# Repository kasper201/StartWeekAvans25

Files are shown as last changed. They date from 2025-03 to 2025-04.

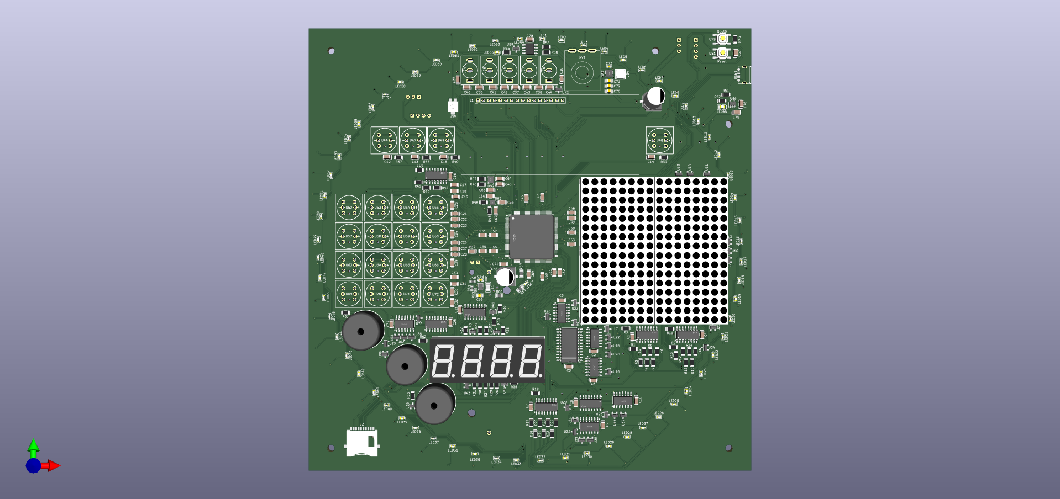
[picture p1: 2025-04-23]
PCB design/PCB_V2/PCB PNG/Top_view.png

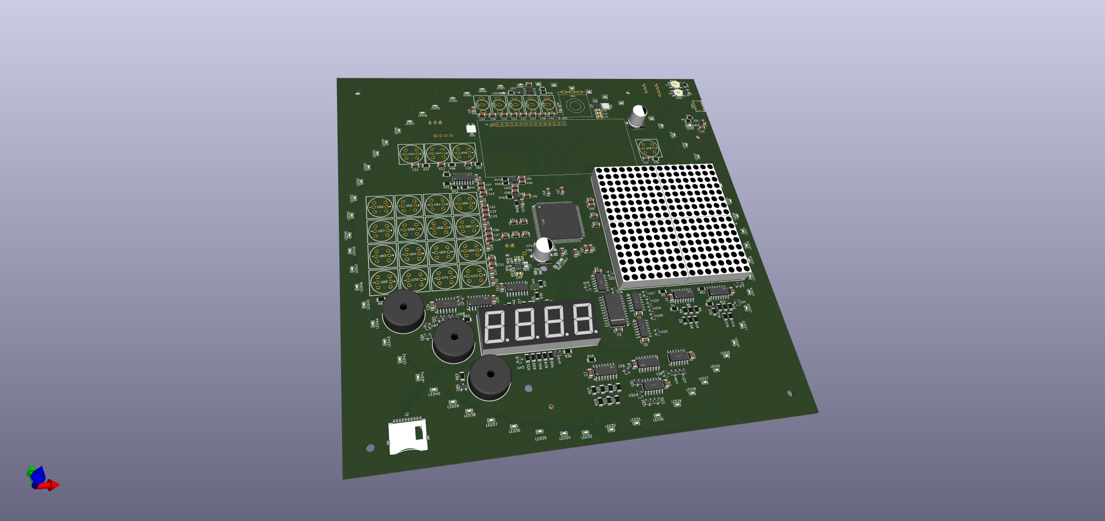
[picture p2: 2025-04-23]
PCB design/PCB_V2/PCB PNG/Side_view.png

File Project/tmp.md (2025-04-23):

# Issues found

# simulator
- printk stops working inside minigame code due to threads?

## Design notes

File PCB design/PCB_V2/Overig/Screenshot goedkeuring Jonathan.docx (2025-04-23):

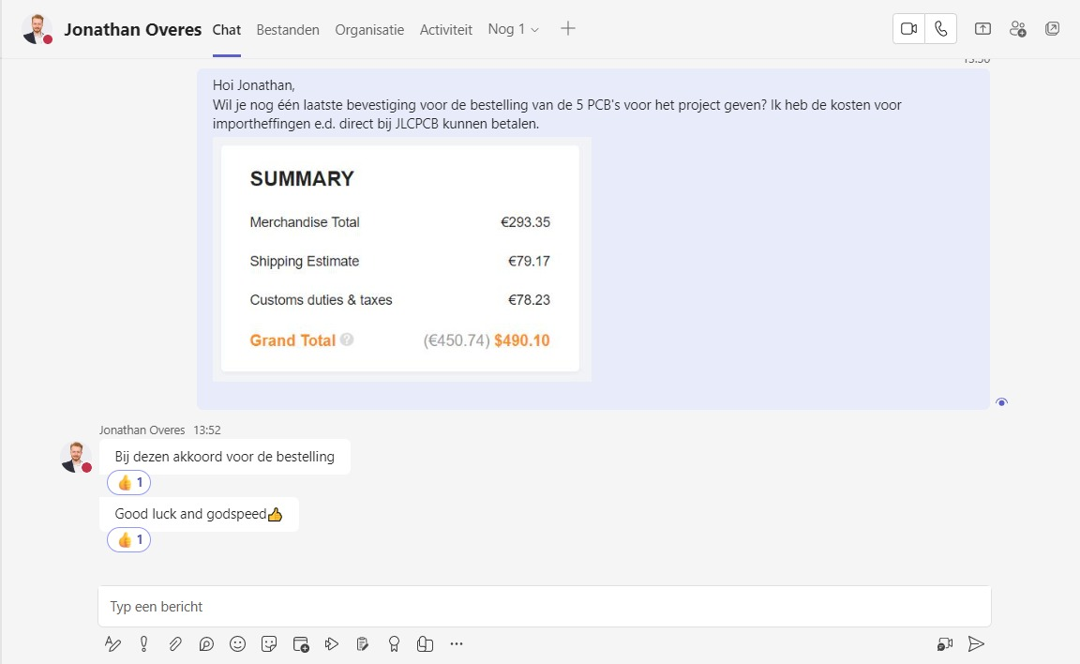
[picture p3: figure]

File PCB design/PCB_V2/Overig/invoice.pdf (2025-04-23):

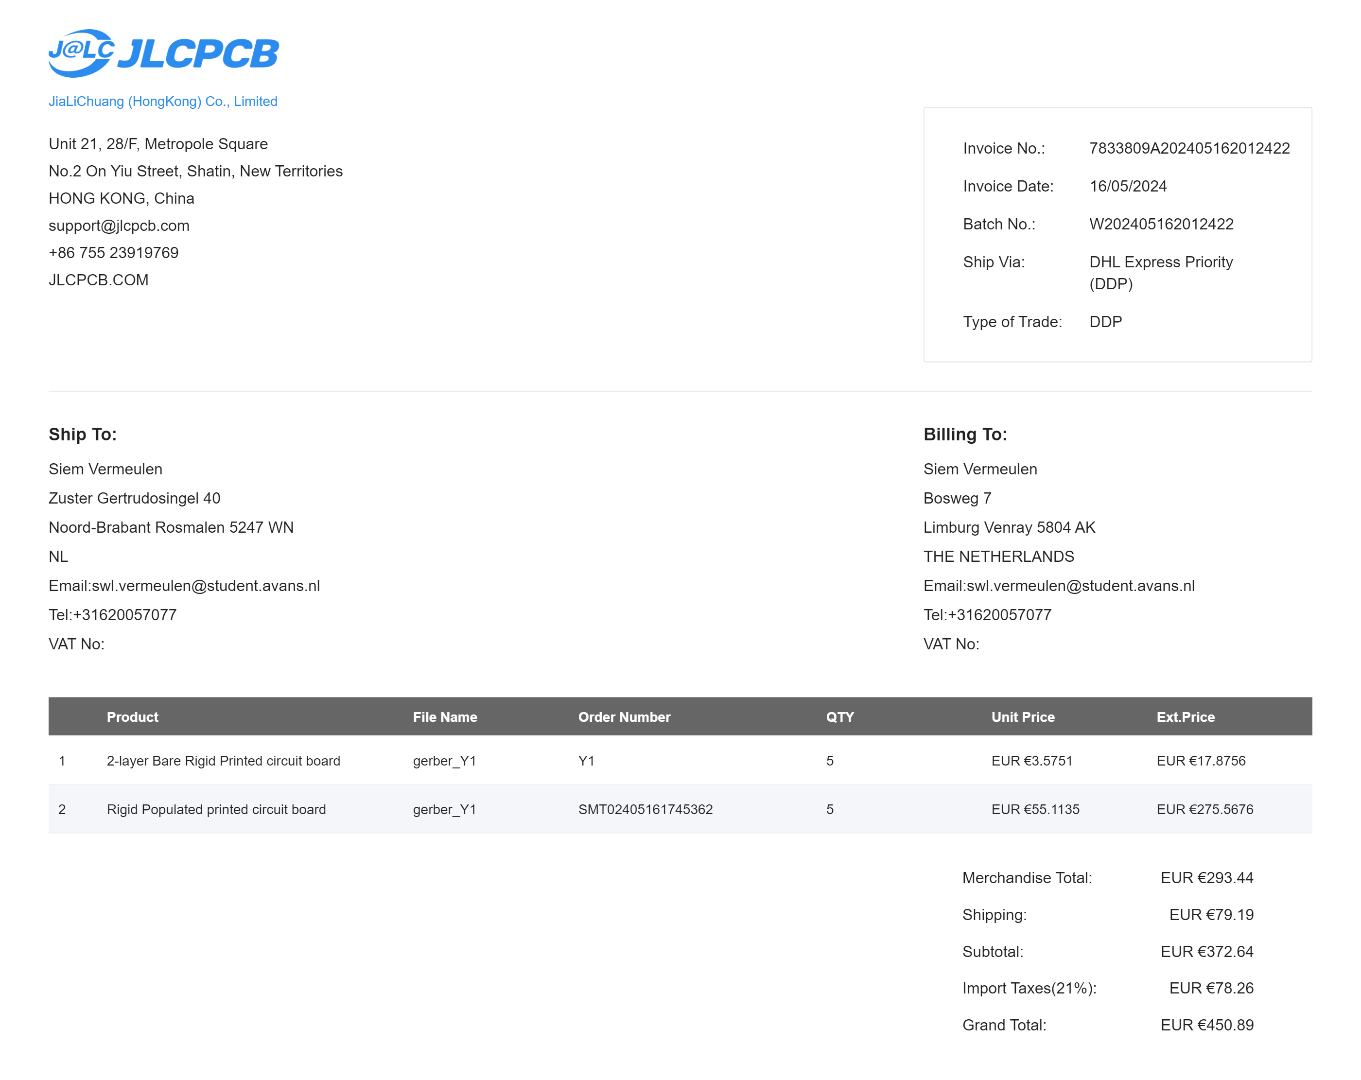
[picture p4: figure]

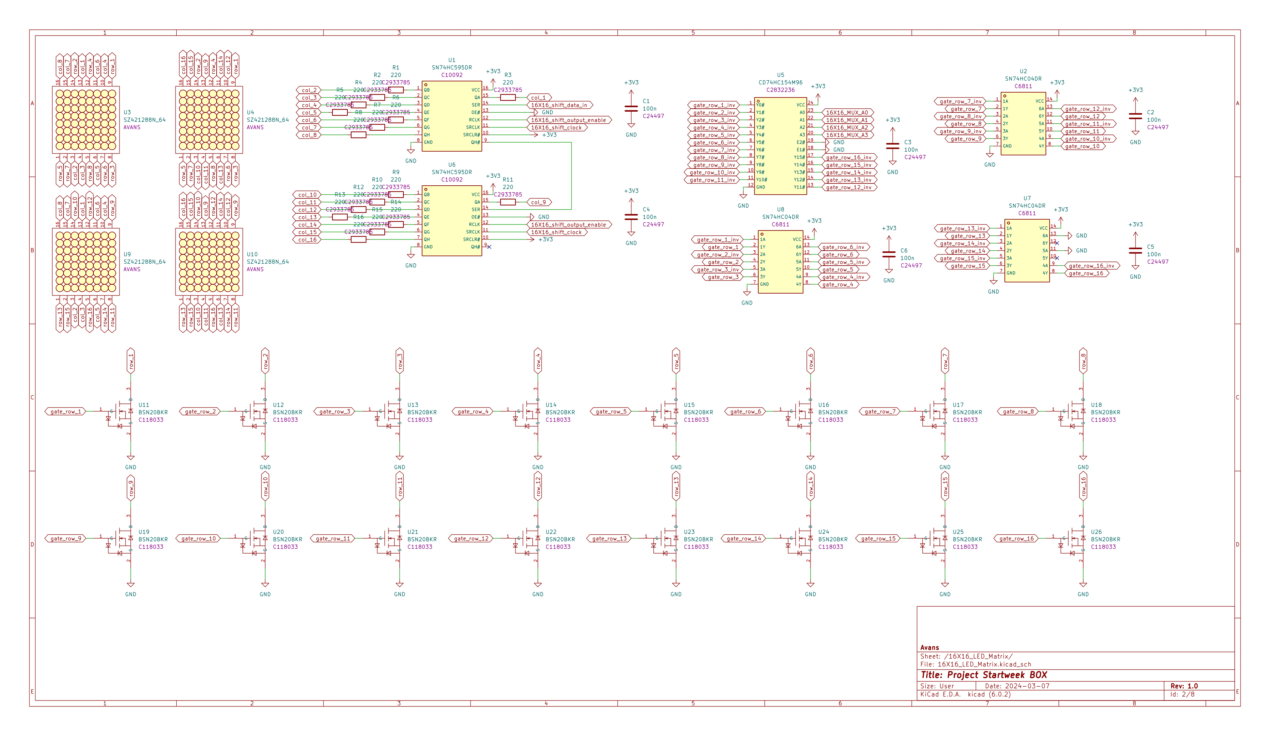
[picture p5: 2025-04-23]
PCB design/PCB_V2/Schematic PNG/PCB_V2-2.png

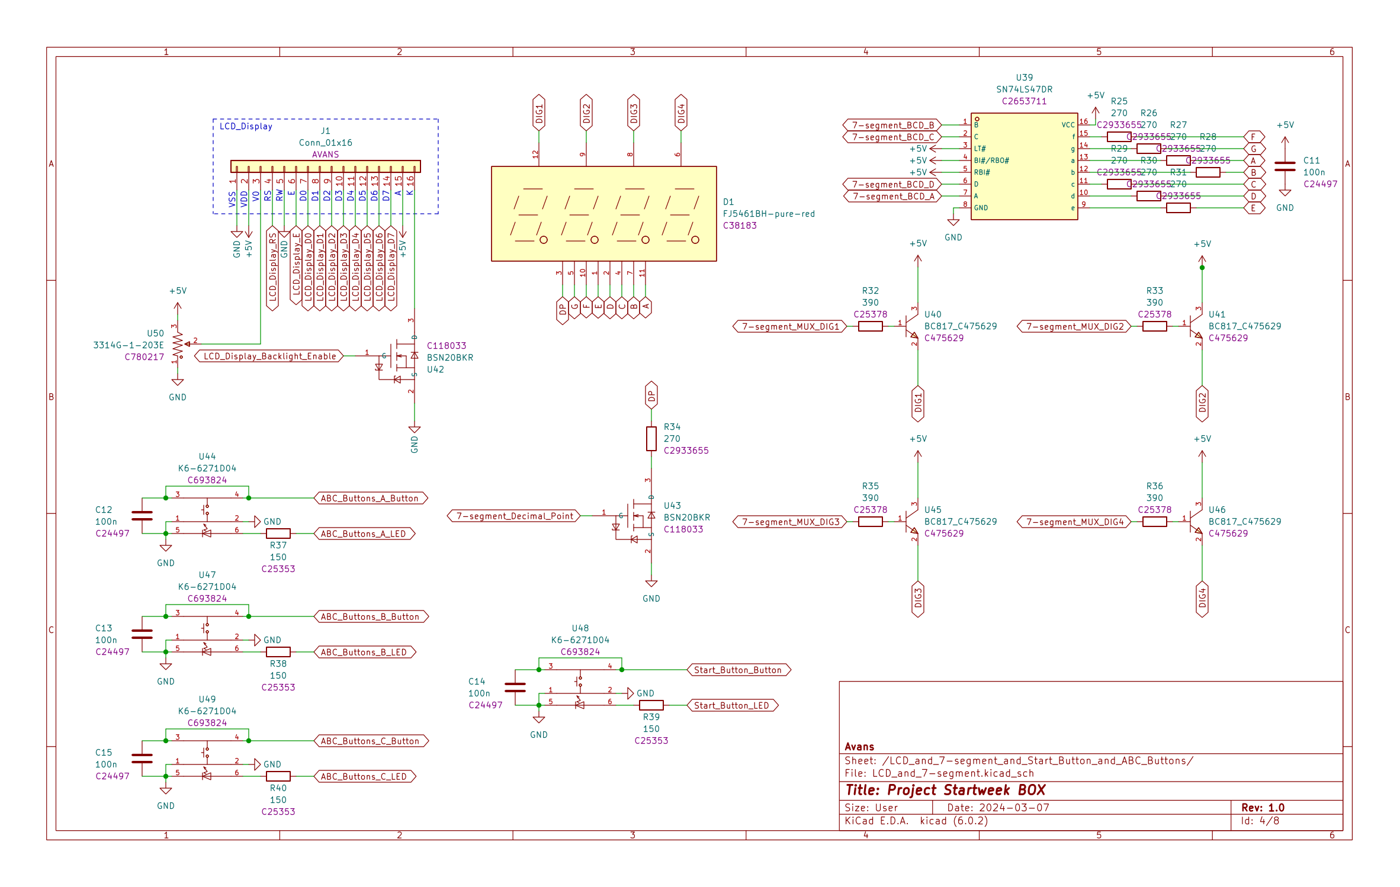
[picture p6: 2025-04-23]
PCB design/PCB_V2/Schematic PNG/PCB_V2-4.png

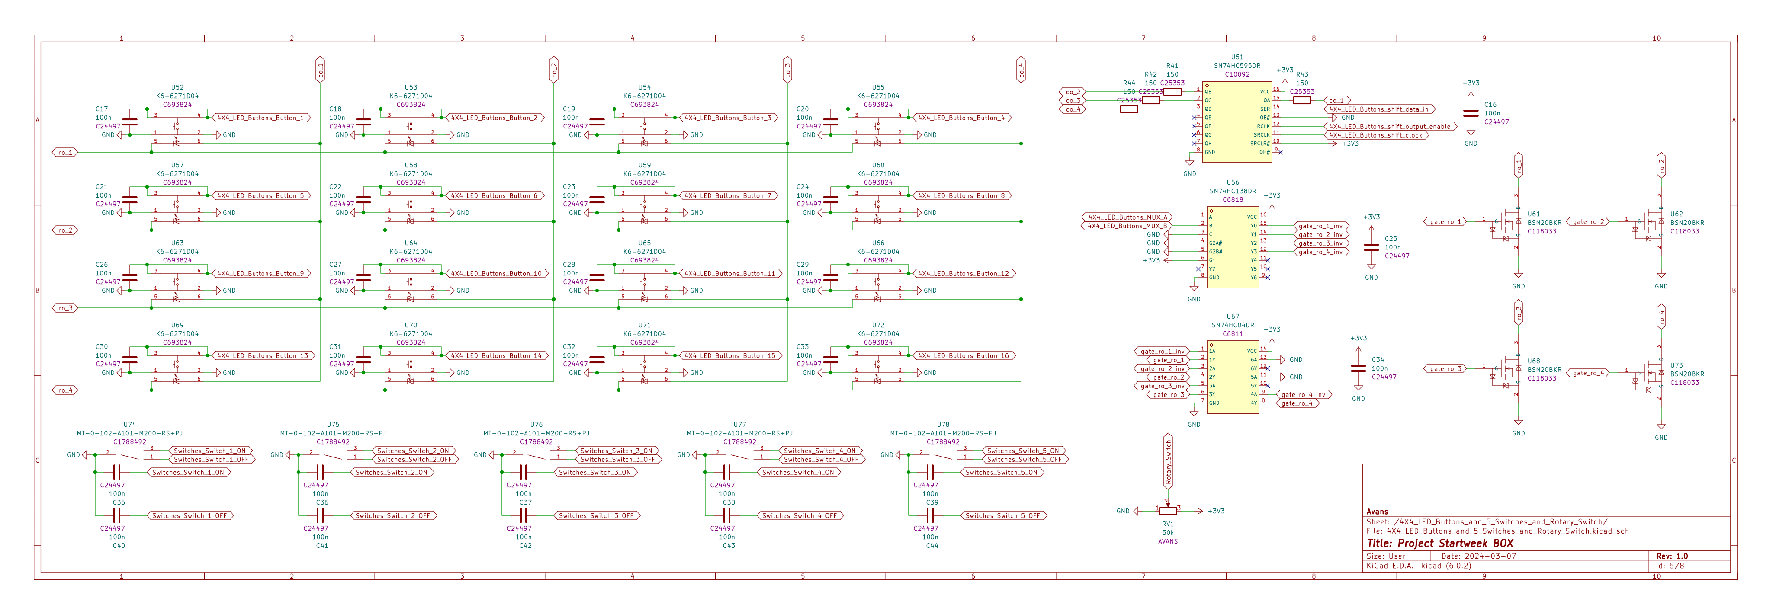
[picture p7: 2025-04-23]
PCB design/PCB_V2/Schematic PNG/PCB_V2-5.png

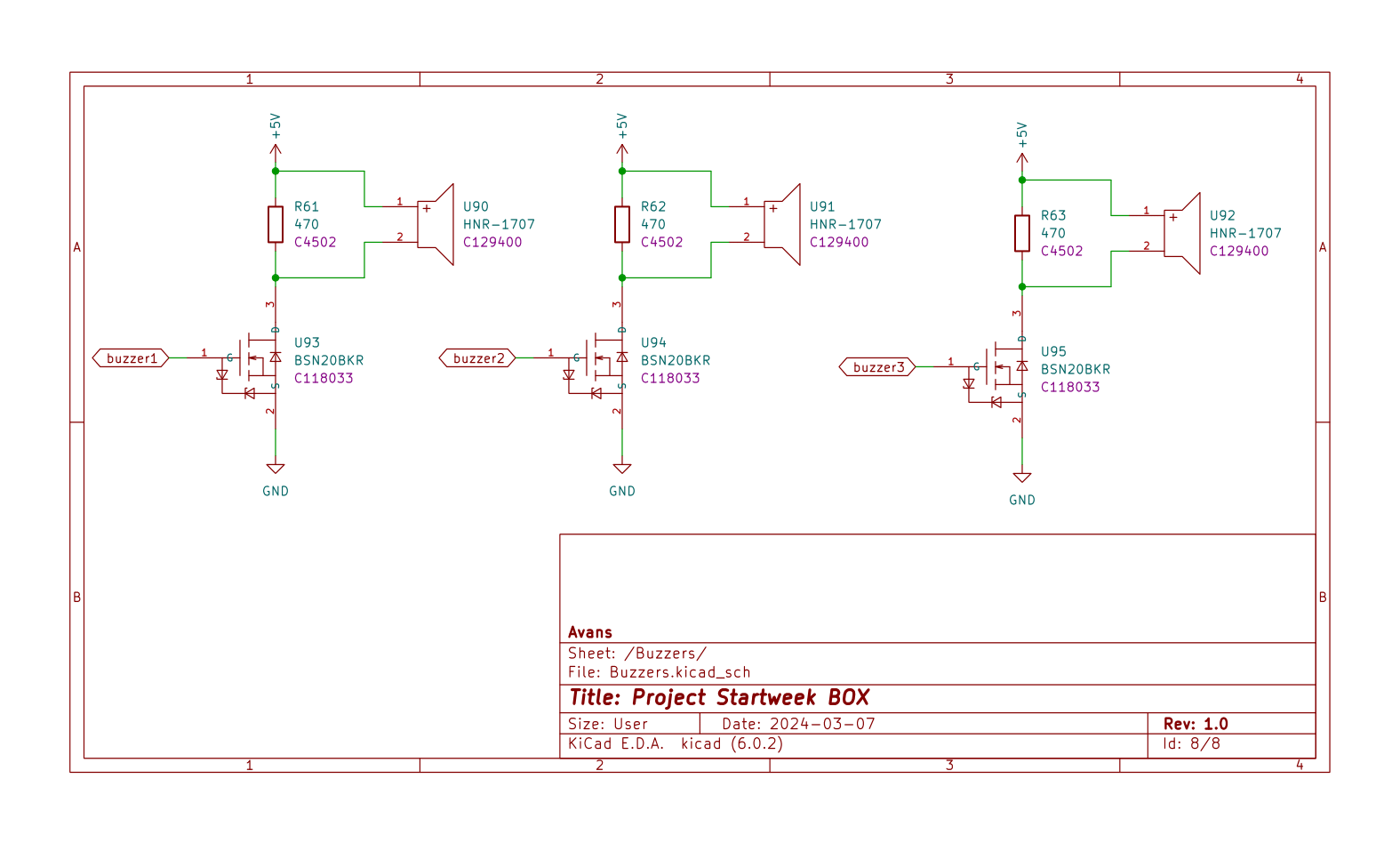
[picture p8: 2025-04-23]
PCB design/PCB_V2/Schematic PNG/PCB_V2-8.png

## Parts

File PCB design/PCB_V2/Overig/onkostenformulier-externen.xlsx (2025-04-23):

Onkostenformulier externen
Gegevens externe
Naam: | Siem Vermeulen |  |  | Dienst Financiën en Studentenadministratie
Adres: | Bosweg 7 | Naam bank: | Rabobank
Postcode & woonplaats: | 5804AK, Venray | IBAN nummer: | NL92RABO0301981418
Telefoonnummer: | 620057077 |  | Let op: volledig IBAN nummer invullen.
Geboortedatum: | 2003-06-25 |  | Alleen bij buitenlandse bank
Academie/diensteenheid: | ATD ETTI project Startweek | BIC:
Kostenplaats | 171100
Reiskosten (vergoeding is maximaal 19 cent per kilometer)
Datum | Reiskosten van - naar | Aantal KM | Tarief | Bedrag (in €)
 |  |  | €0.19 | €0.00
 |  |  | €0.19 | €0.00
 |  |  | €0.19 | €0.00
 |  |  | €0.19 | €0.00
 |  |  | €0.19 | €0.00
Totaal reiskosten |  |  |  | €0.00
OV-kosten*
Datum | OV-kosten van - naar |  |  | Bedrag (in €)
 |  |  |  | €0.00
 |  |  |  | €0.00
 |  |  |  | €0.00
 |  |  |  | €0.00
Totaal OV-kosten |  |  |  | €0.00
Overige kosten*
Datum | Omschrijving overig kosten |  |  | Bedrag (in €)
2024-05-16 | PCB besteld bij JLCPCB voor project Startweek |  |  | €450.89
 |  |  |  | €0.00
 |  |  |  | €0.00
 |  |  |  | €0.00
Totaal overige kosten |  |  |  | €450.89
Totaalbedrag onkostendeclaratie |  |  |  | €450.89
* OV & overige kosten worden alleen uitbetaald indien originele bonnen en/of facturen zijn toegevoegd.
Ondertekening door externe |  |  |  |  | Ondertekening voor akkoord
Datum: | 2024-05-16 |  | Datum:
 |  |  | Naam budgethouder/directeur:
Handtekening externe:
 |  |  | Handtekening budgethouder/directeur:
Budgethouder tekent voor akkoord en bevestigd tevens hierbij dat identiteit van externe is vastgesteld.
Is het formulier volledig ingevuld en ondertekend? Stuur deze (inclusief bonnen) dan naar: |  |  |  | Service Unit Financiën
 |  |  |  | Bijster 7-21, Breda
 | Vragen? Neem dan contact op met: | crediteuren@avans.nl |  | Kamer DB226
Hieronder in te vullen door de financiële administratie
Crediteurennummer: | …………………………………………………
Boekstuknummer: | …………………………………………………
Kostensoort | Kostenplaats | Kostendrager | Omschrijving |  | Bedrag (in €)

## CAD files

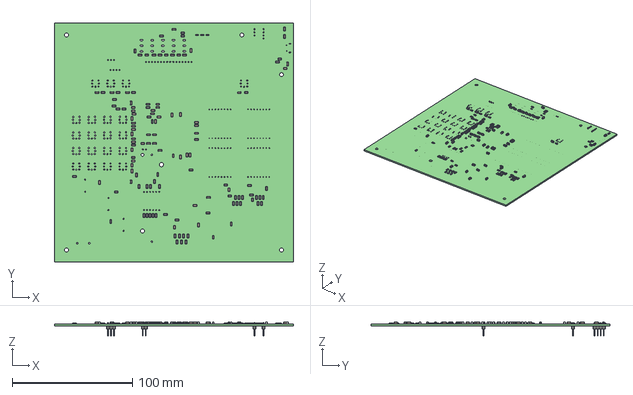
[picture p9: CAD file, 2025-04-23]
PCB design/PCB_V2/PCB_V2.step
199.0 x 199.0 x 11.8 mm
PCB_V2 PCB

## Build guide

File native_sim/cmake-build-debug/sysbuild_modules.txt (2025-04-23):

"mcuboot":"/home/flits/zephyrproject/bootloader/mcuboot":"/home/flits/zephyrproject/bootloader/mcuboot/boot/zephyr/sysbuild"

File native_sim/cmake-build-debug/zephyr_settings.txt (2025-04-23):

# WARNING. THIS FILE IS AUTO-GENERATED. DO NOT MODIFY!
#
# This file contains build system settings derived from your modules.
#
# Modules may be set via ZEPHYR_MODULES, ZEPHYR_EXTRA_MODULES,
# and/or the west manifest file.
#
# See the Modules guide for more information.
"DTS_ROOT":"/home/flits/zephyrproject/modules/hal/atmel"
"DTS_ROOT":"/home/flits/zephyrproject/modules/hal/espressif"
"DTS_ROOT":"/home/flits/zephyrproject/modules/hal/gigadevice"
"DTS_ROOT":"/home/flits/zephyrproject/modules/hal/nuvoton"
"DTS_ROOT":"/home/flits/zephyrproject/modules/hal/nxp"
"DTS_ROOT":"/home/flits/zephyrproject/modules/hal/stm32"

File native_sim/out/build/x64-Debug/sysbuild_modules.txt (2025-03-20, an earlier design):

"mcuboot":"C:/Users/verpl/zephyrproject/bootloader/mcuboot":"C:/Users/verpl/zephyrproject/bootloader/mcuboot/boot/zephyr/sysbuild"

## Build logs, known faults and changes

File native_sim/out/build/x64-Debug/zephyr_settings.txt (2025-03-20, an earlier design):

# WARNING. THIS FILE IS AUTO-GENERATED. DO NOT MODIFY!
#
# This file contains build system settings derived from your modules.
#
# Modules may be set via ZEPHYR_MODULES, ZEPHYR_EXTRA_MODULES,
# and/or the west manifest file.
#
# See the Modules guide for more information.
"DTS_ROOT":"C:/Users/verpl/zephyrproject/modules/hal/adi"
"DTS_ROOT":"C:/Users/verpl/zephyrproject/modules/hal/atmel"
"DTS_ROOT":"C:/Users/verpl/zephyrproject/modules/hal/espressif"
"DTS_ROOT":"C:/Users/verpl/zephyrproject/modules/hal/gigadevice"
"DTS_ROOT":"C:/Users/verpl/zephyrproject/modules/hal/microchip"
"DTS_ROOT":"C:/Users/verpl/zephyrproject/modules/hal/nuvoton"
"DTS_ROOT":"C:/Users/verpl/zephyrproject/modules/hal/nxp"
"DTS_ROOT":"C:/Users/verpl/zephyrproject/modules/hal/stm32"

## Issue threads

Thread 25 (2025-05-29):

Standardize the showing of scores after games

TotallyOriginalUsername, 2025-05-29:
Currently not every minigame shows the final score once the game has ended

TotallyOriginalUsername, 2025-06-10:
There is no help needed, I could not work on this improvement whilst multiple minigames(with each their own way of showing score at the end) were under PR review

Closed 2025-06-10.

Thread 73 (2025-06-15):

Magnetometer does not reliably point towards the same location.

kasper201, 2025-06-15:
The magnetometer is unable to locate the north reliably. This must either be fixed or a different method should be used for displaying direction.

Closed 2025-07-17.

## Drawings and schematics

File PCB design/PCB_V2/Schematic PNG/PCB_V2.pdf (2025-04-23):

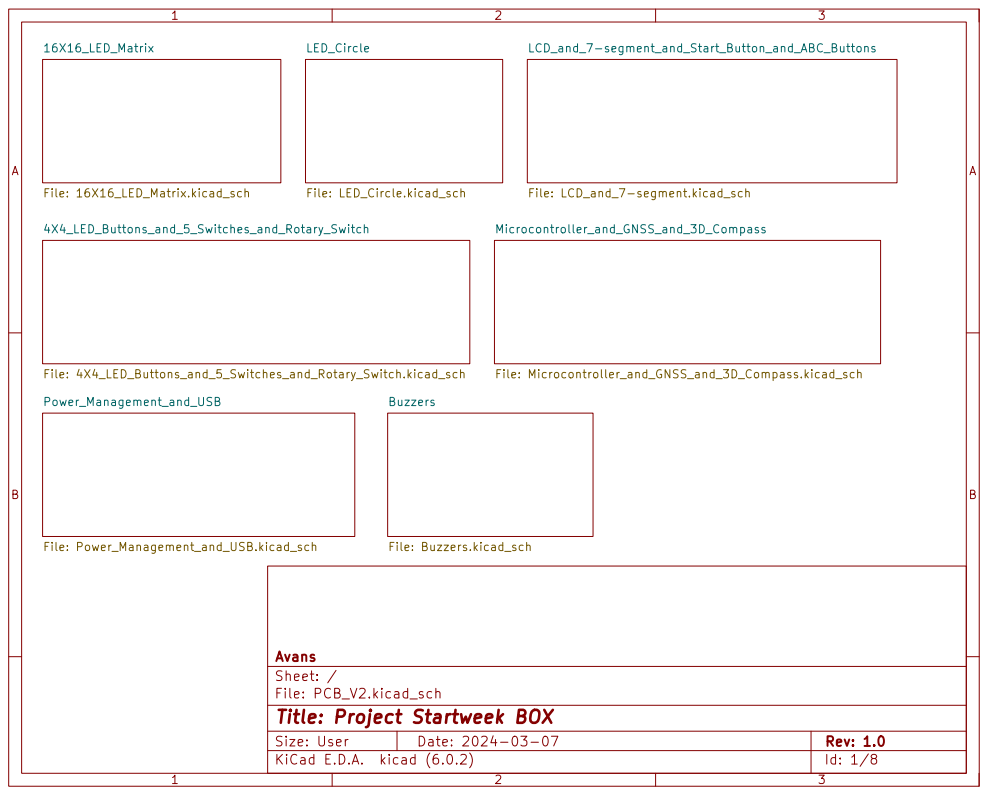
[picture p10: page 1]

File: Microcontroller_and_GNSS_and_3D_Compass.kicad_sch Buzzers File: Buzzers.kicad_sch

Id: 1/8 Title: Project Startweek BOX

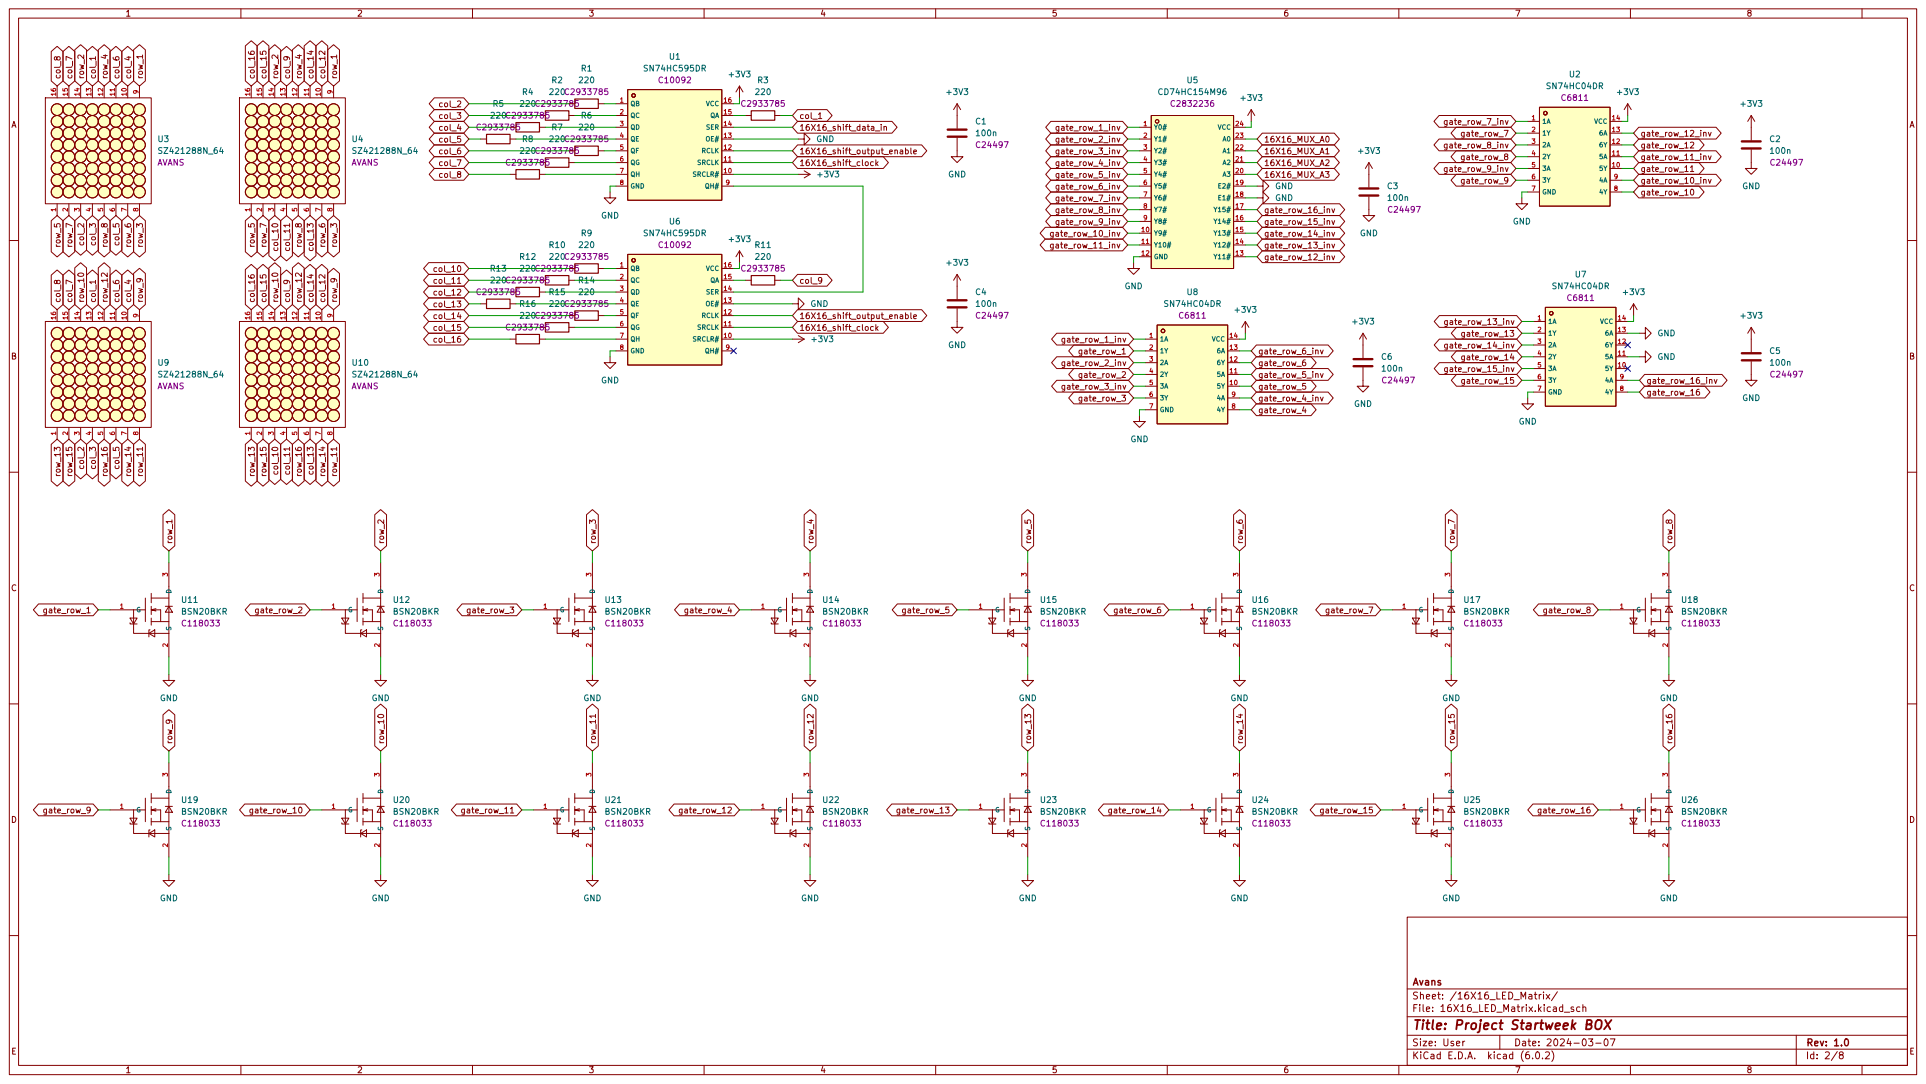
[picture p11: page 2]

File: 16X16_LED_Matrix.kicad_sch
Id: 2/8 Title: Project Startweek BOX

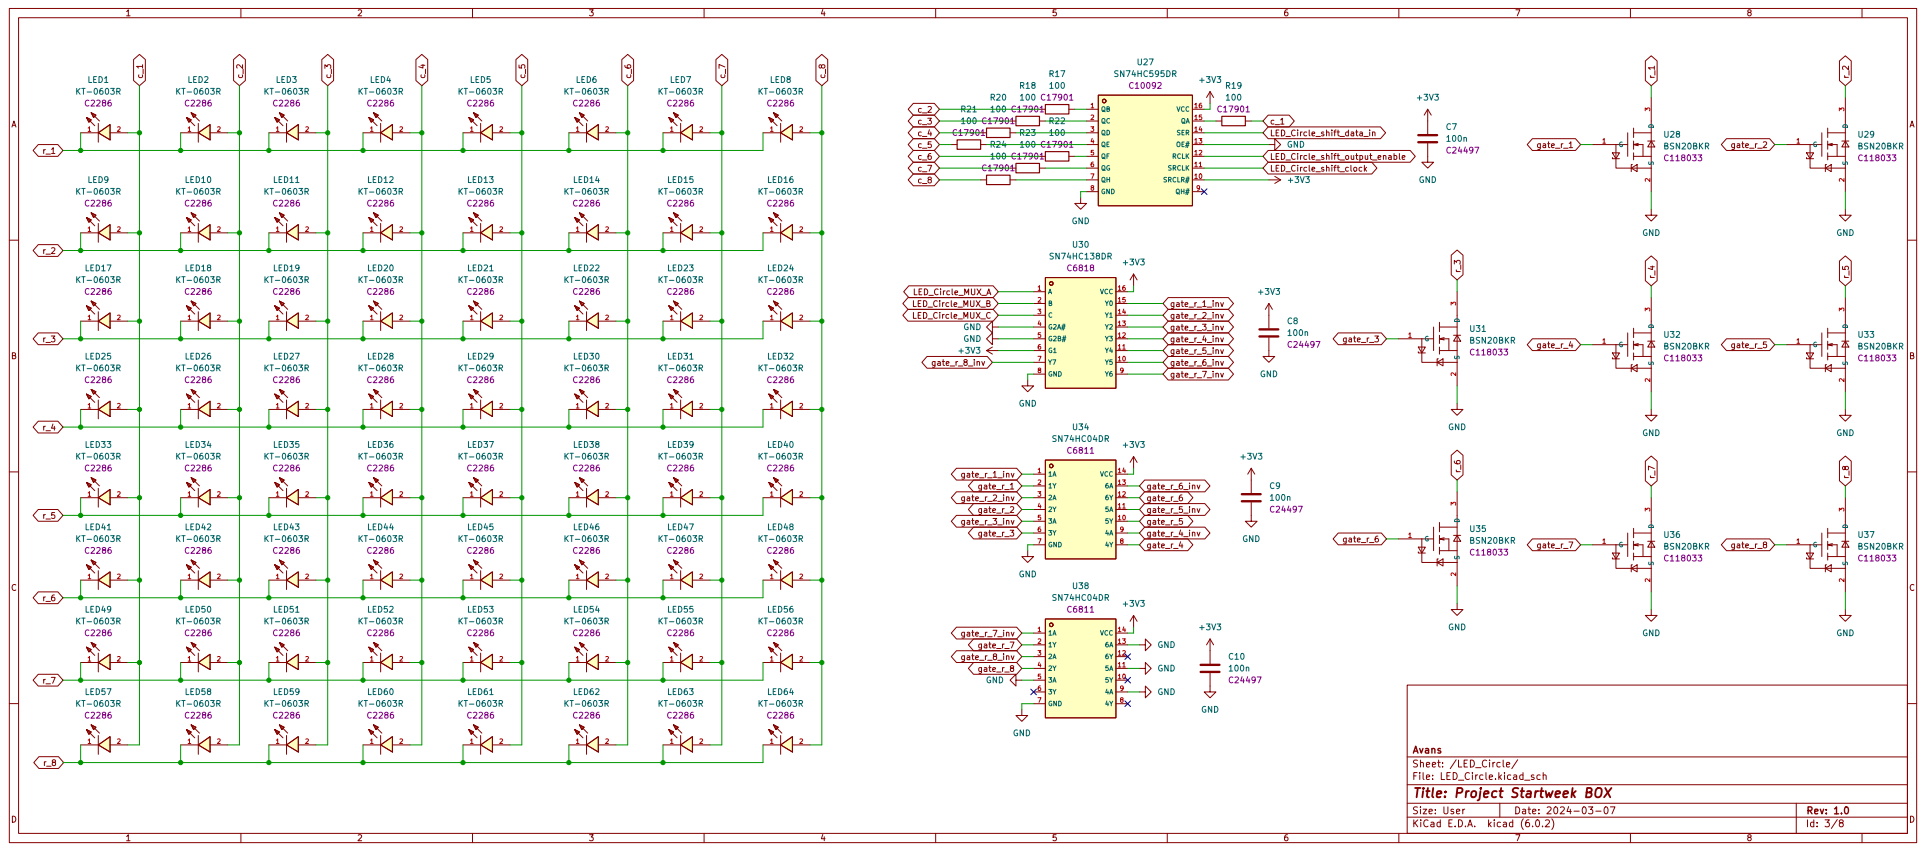
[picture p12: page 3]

File: LED_Circle.kicad_sch
Id: 3/8 Title: Project Startweek BOX

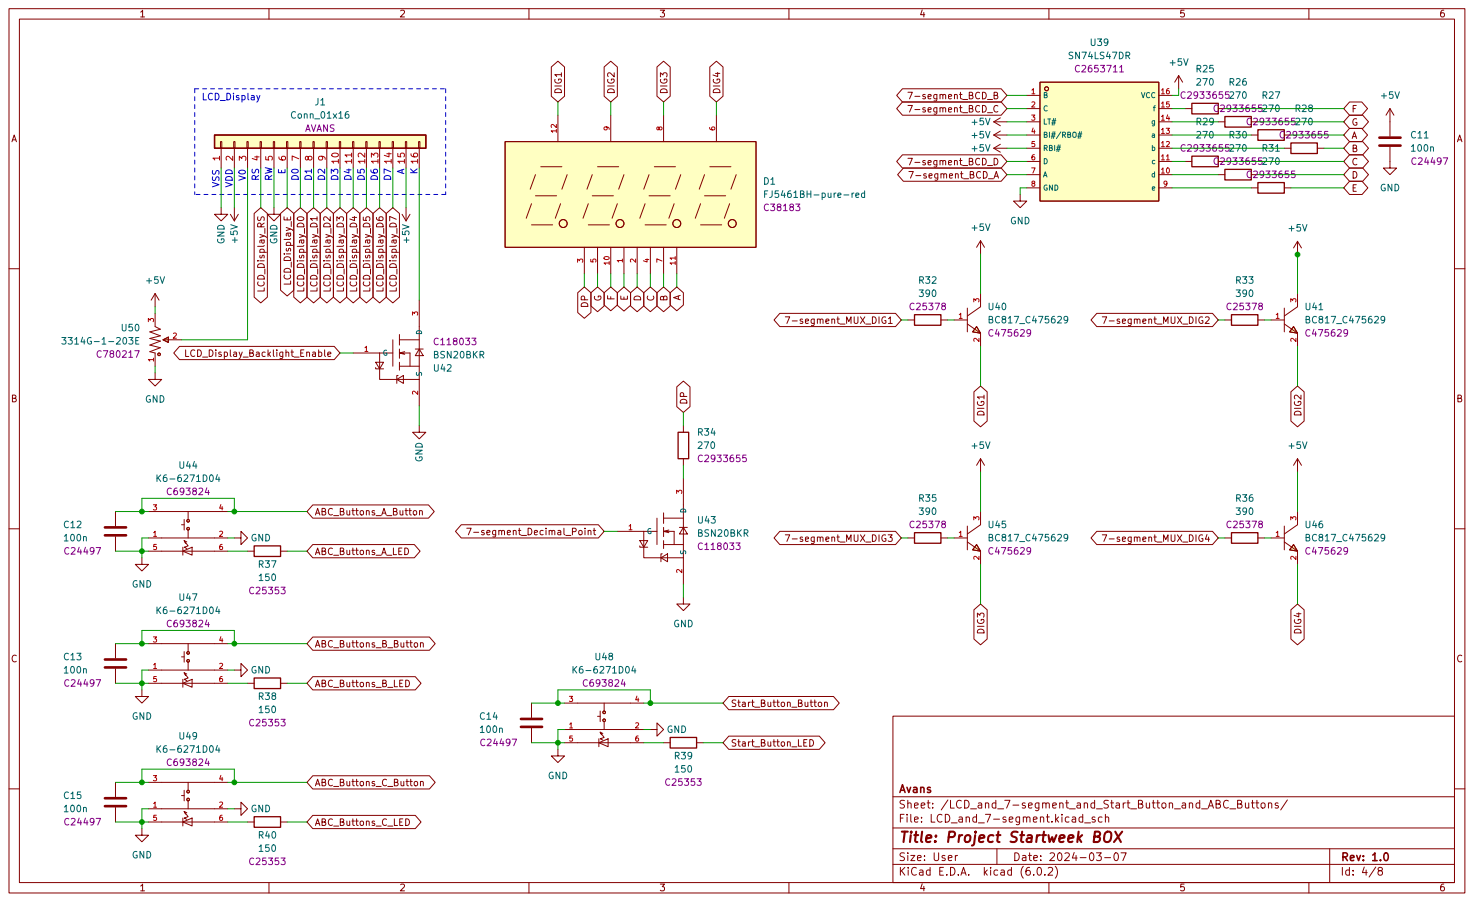
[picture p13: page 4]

File: LCD_and_7-segment.kicad_sch
Id: 4/8 Title: Project Startweek BOX

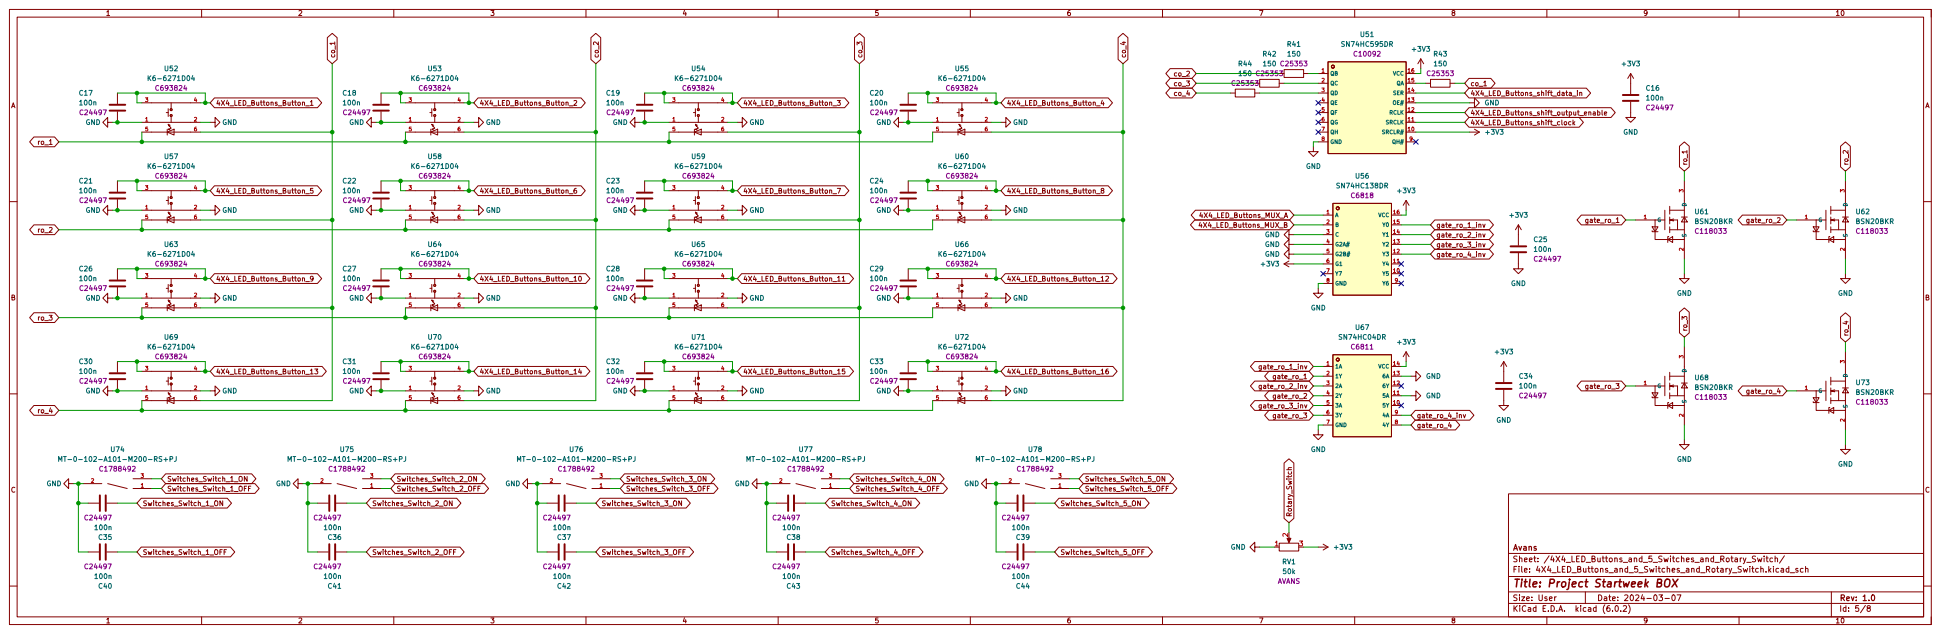
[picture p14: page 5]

3 U78 MT-0-102-A101-M200-RS+PJ C1788492 GND

File: 4X4_LED_Buttons_and_5_Switches_and_Rotary_Switch.kicad_sch
Id: 5/8 Title: Project Startweek BOX

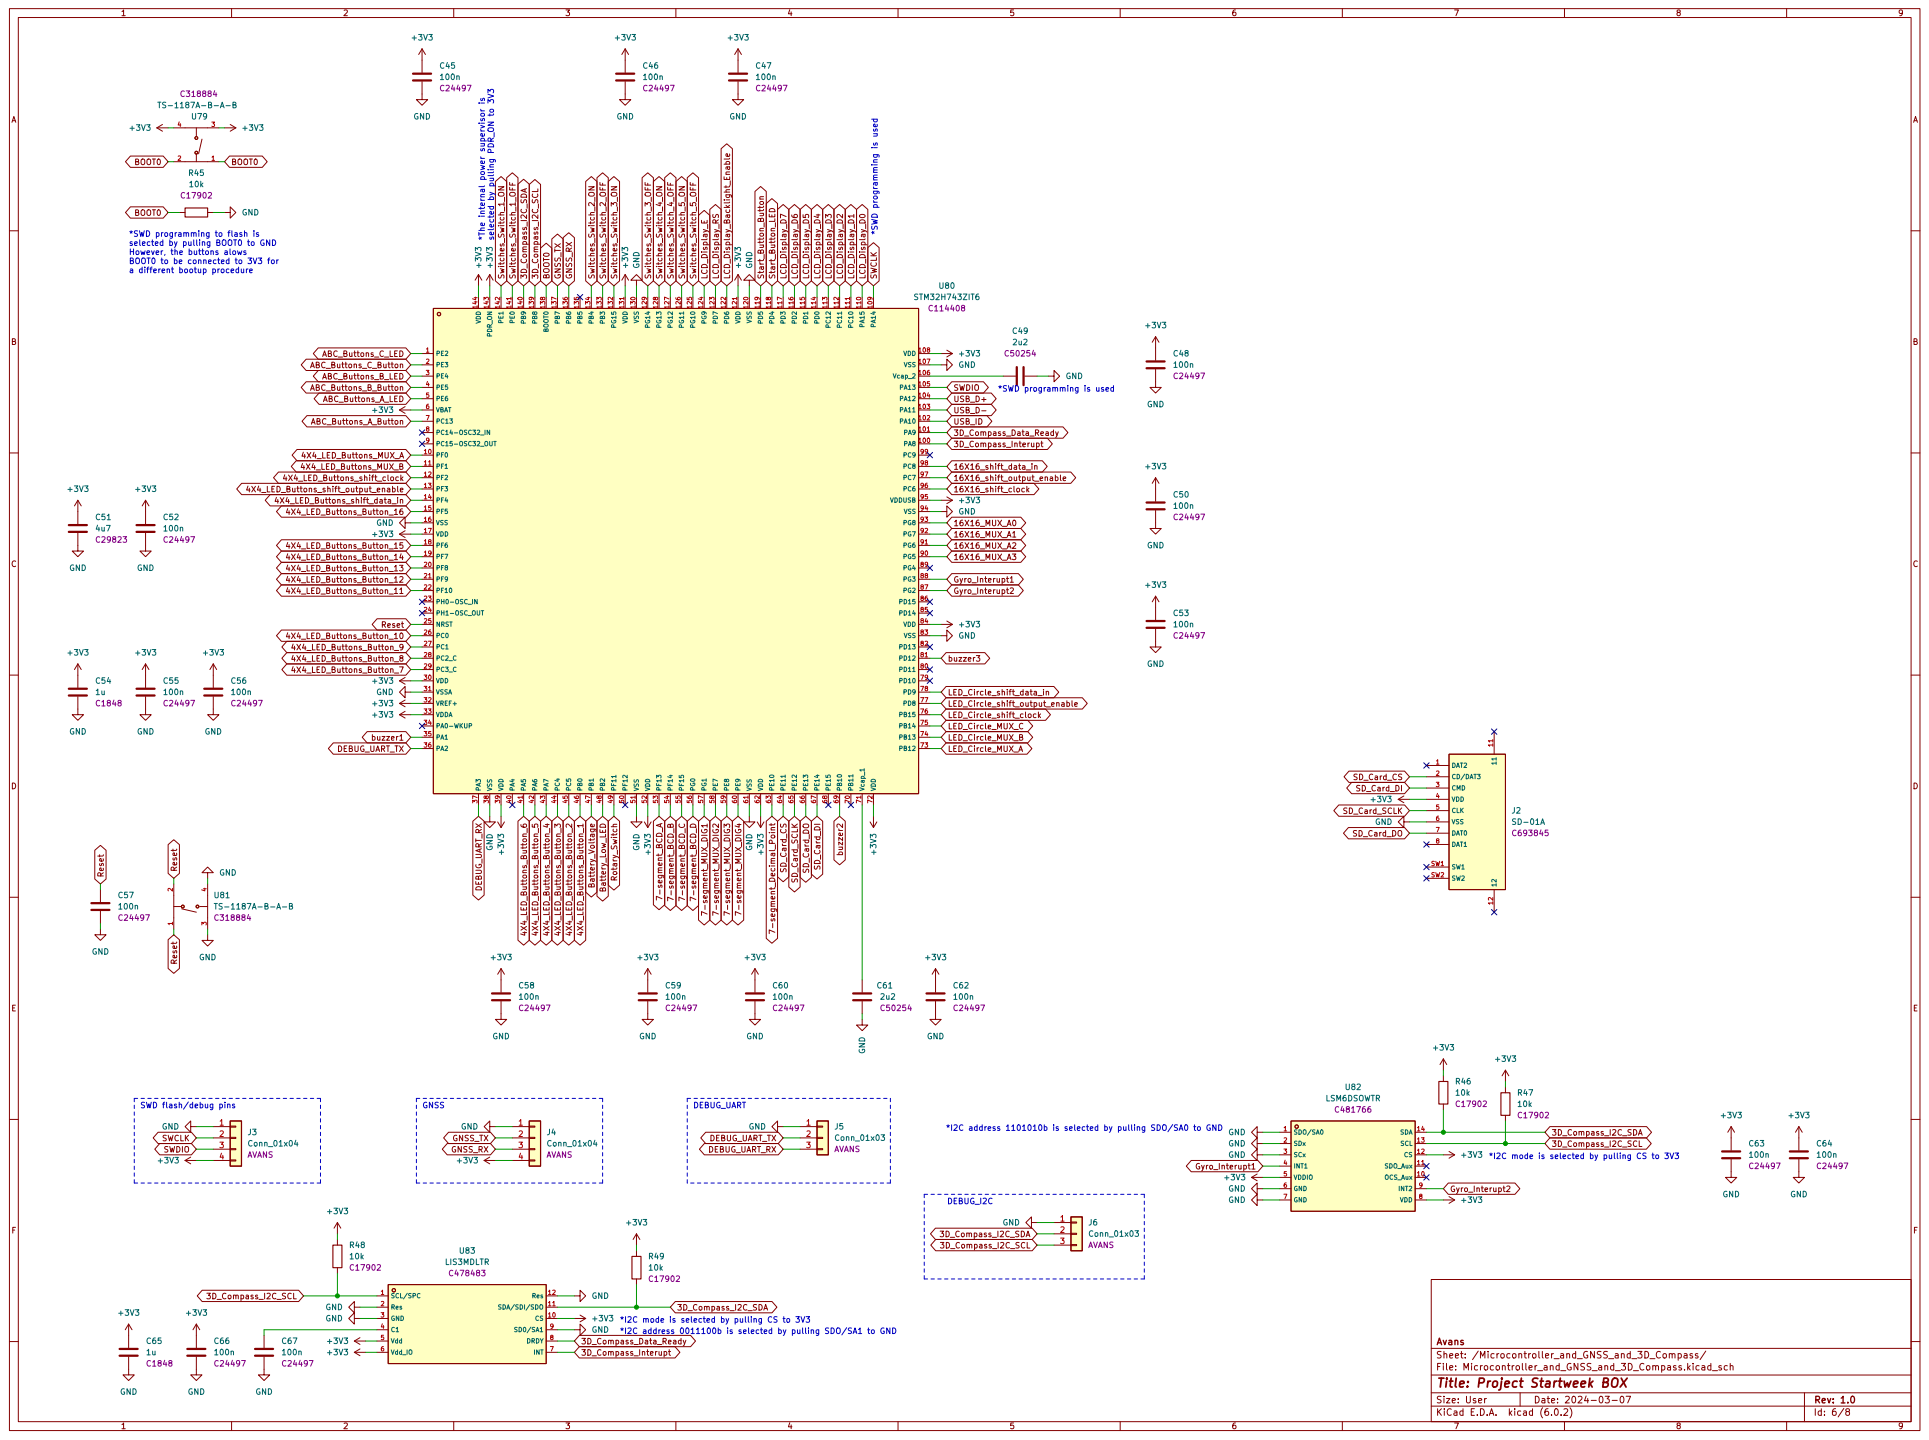
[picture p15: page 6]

*SWD programming to flash is
selected by pulling BOOT0 to GND
However, the buttons alows BOOT0 to be connected to 3V3 for a different bootup procedure

*SWD programming is used

*I2C mode is selected by pulling CS to 3V3 DEBUG_UART

*I2C address 1101010b is selected by pulling SDO/SA0 to GND

*I2C mode is selected by pulling CS to 3V3

File: Microcontroller_and_GNSS_and_3D_Compass.kicad_sch
Id: 6/8 Title: Project Startweek BOX

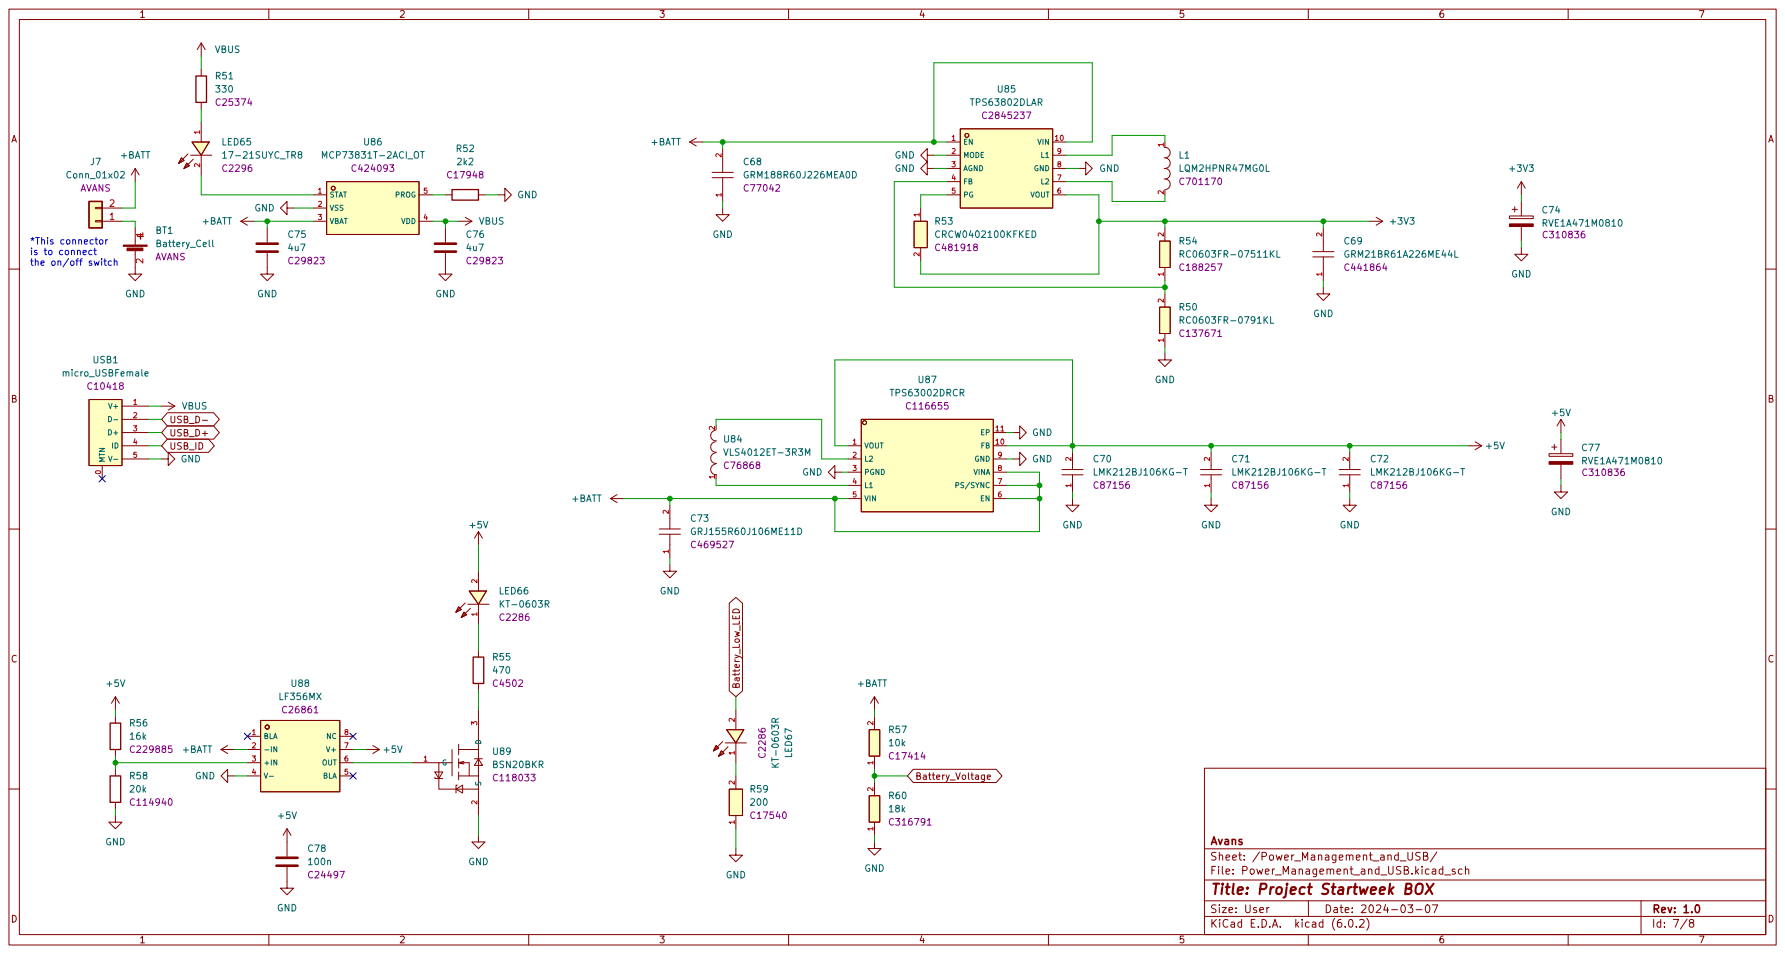
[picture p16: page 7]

*This connector
is to connect
the on/off switch

File: Power_Management_and_USB.kicad_sch
Id: 7/8 Title: Project Startweek BOX

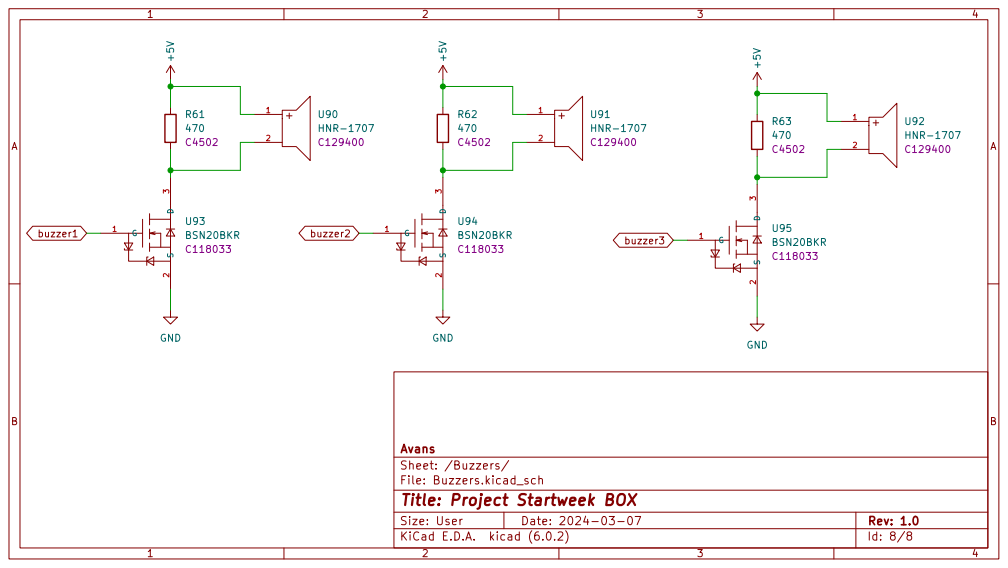
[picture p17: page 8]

File: Buzzers.kicad_sch Sheet: /Buzzers/ Avans R61

Id: 8/8 Title: Project Startweek BOX

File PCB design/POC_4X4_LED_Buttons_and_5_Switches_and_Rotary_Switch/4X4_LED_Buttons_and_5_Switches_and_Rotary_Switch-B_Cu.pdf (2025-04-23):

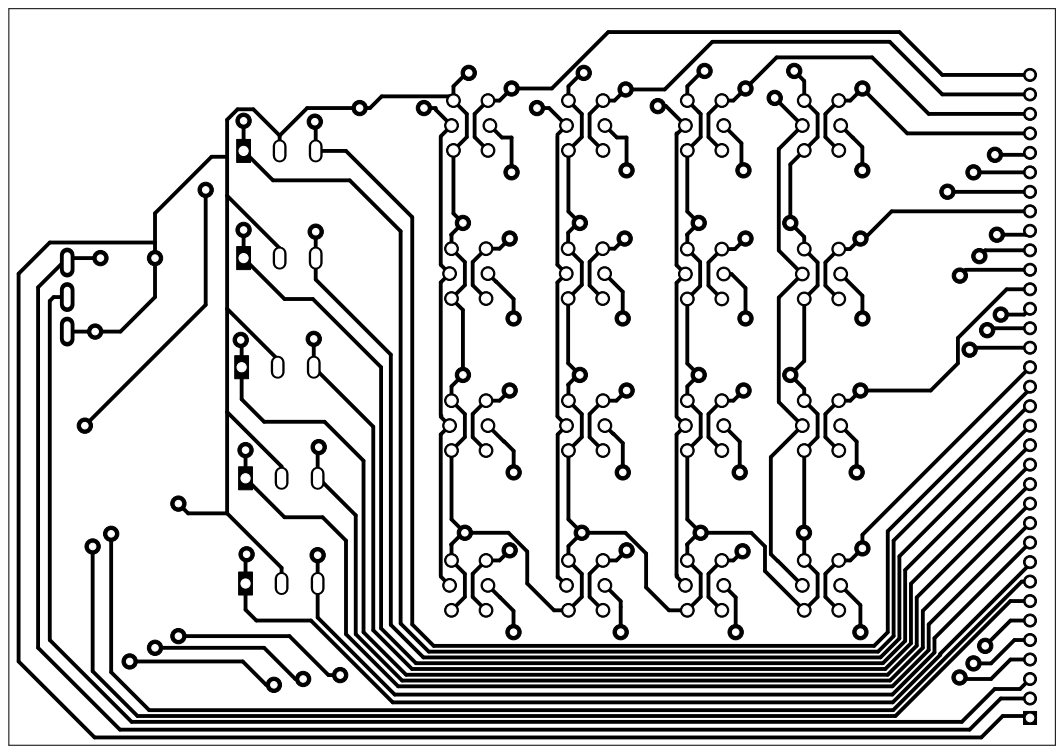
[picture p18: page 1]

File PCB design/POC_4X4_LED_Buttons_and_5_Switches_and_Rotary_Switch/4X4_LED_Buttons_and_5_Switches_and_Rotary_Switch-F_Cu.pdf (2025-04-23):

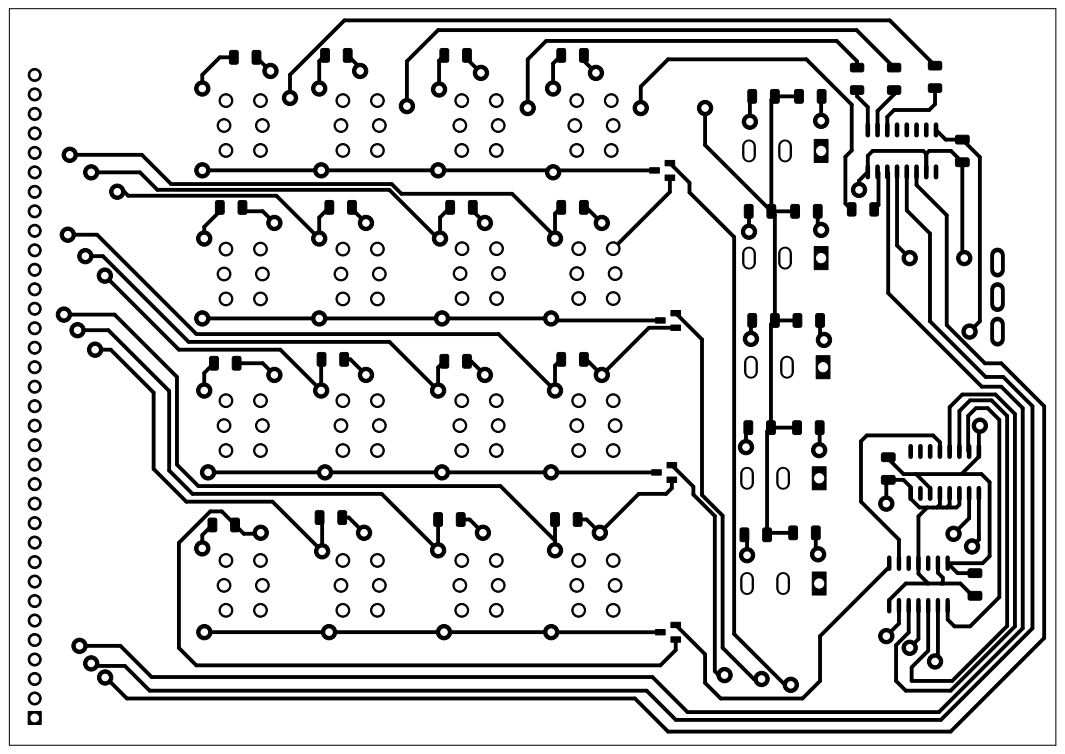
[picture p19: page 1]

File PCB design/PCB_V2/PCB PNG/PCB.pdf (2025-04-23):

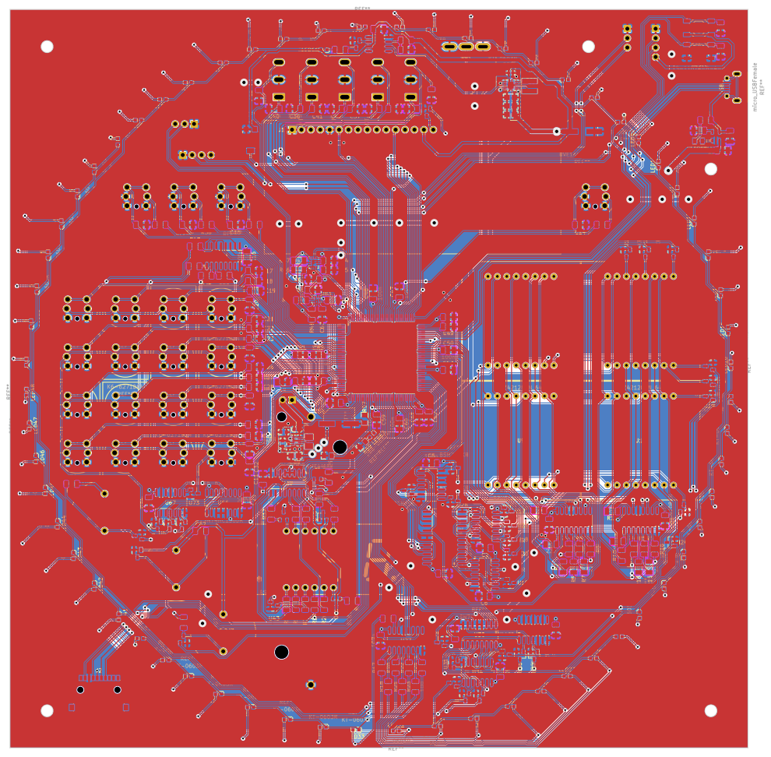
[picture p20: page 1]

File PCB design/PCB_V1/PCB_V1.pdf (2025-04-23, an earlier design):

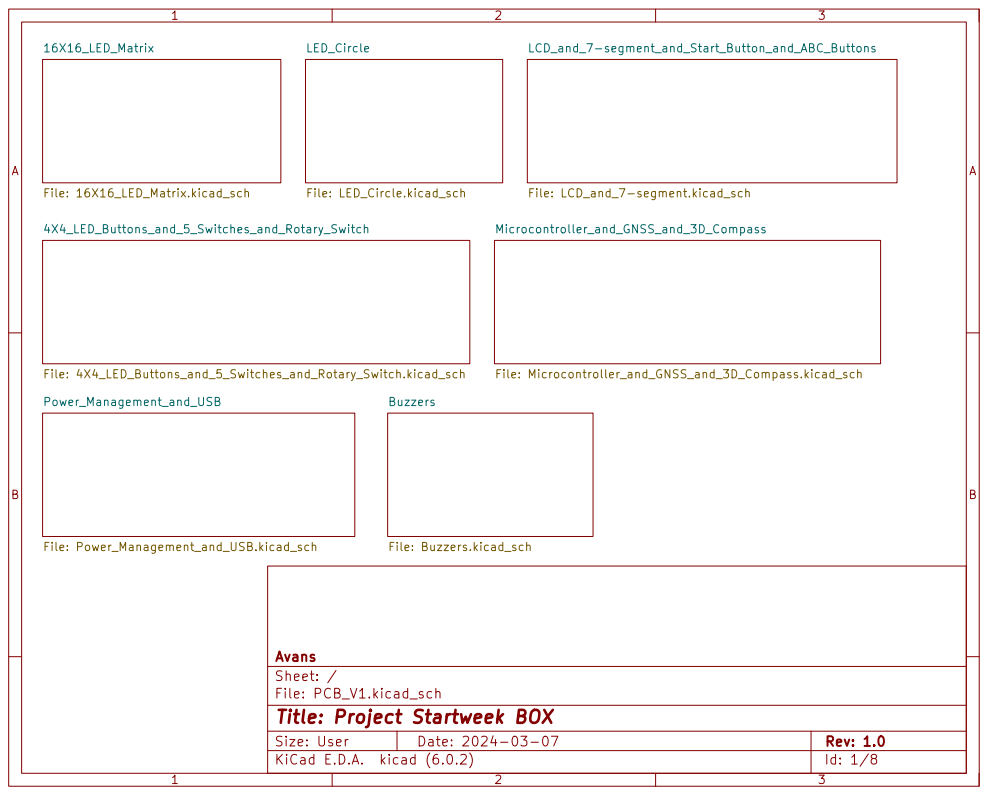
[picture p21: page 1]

File: Microcontroller_and_GNSS_and_3D_Compass.kicad_sch Buzzers File: Buzzers.kicad_sch

Id: 1/8 Title: Project Startweek BOX


File: 16X16_LED_Matrix.kicad_sch
Id: 2/8 Title: Project Startweek BOX


File: LED_Circle.kicad_sch
Id: 3/8 Title: Project Startweek BOX


File: LCD_and_7-segment.kicad_sch
Id: 4/8 Title: Project Startweek BOX


3 U78 MT-0-102-A101-M200-RS+PJ C1788492 GND

File: 4X4_LED_Buttons_and_5_Switches_and_Rotary_Switch.kicad_sch
Id: 5/8 Title: Project Startweek BOX


*SWD programming to flash is
selected by pulling BOOT0 to GND
However, the 0ohm resistor alows BOOT0 to be connected to 3V3 for a different bootup procedure

*I2C mode is selected by pulling CS to 3V3
*I2C address 0011100b is selected by pulling SDO/SA1 to GND

File: Microcontroller_and_GNSS_and_3D_Compass.kicad_sch
Id: 6/8 Title: Project Startweek BOX


*This connector
is to connect
the on/off switch

File: Power_Management_and_USB.kicad_sch
Id: 7/8 Title: Project Startweek BOX


File: Buzzers.kicad_sch Sheet: /Buzzers/ Avans

Id: 8/8 Title: Project Startweek BOX

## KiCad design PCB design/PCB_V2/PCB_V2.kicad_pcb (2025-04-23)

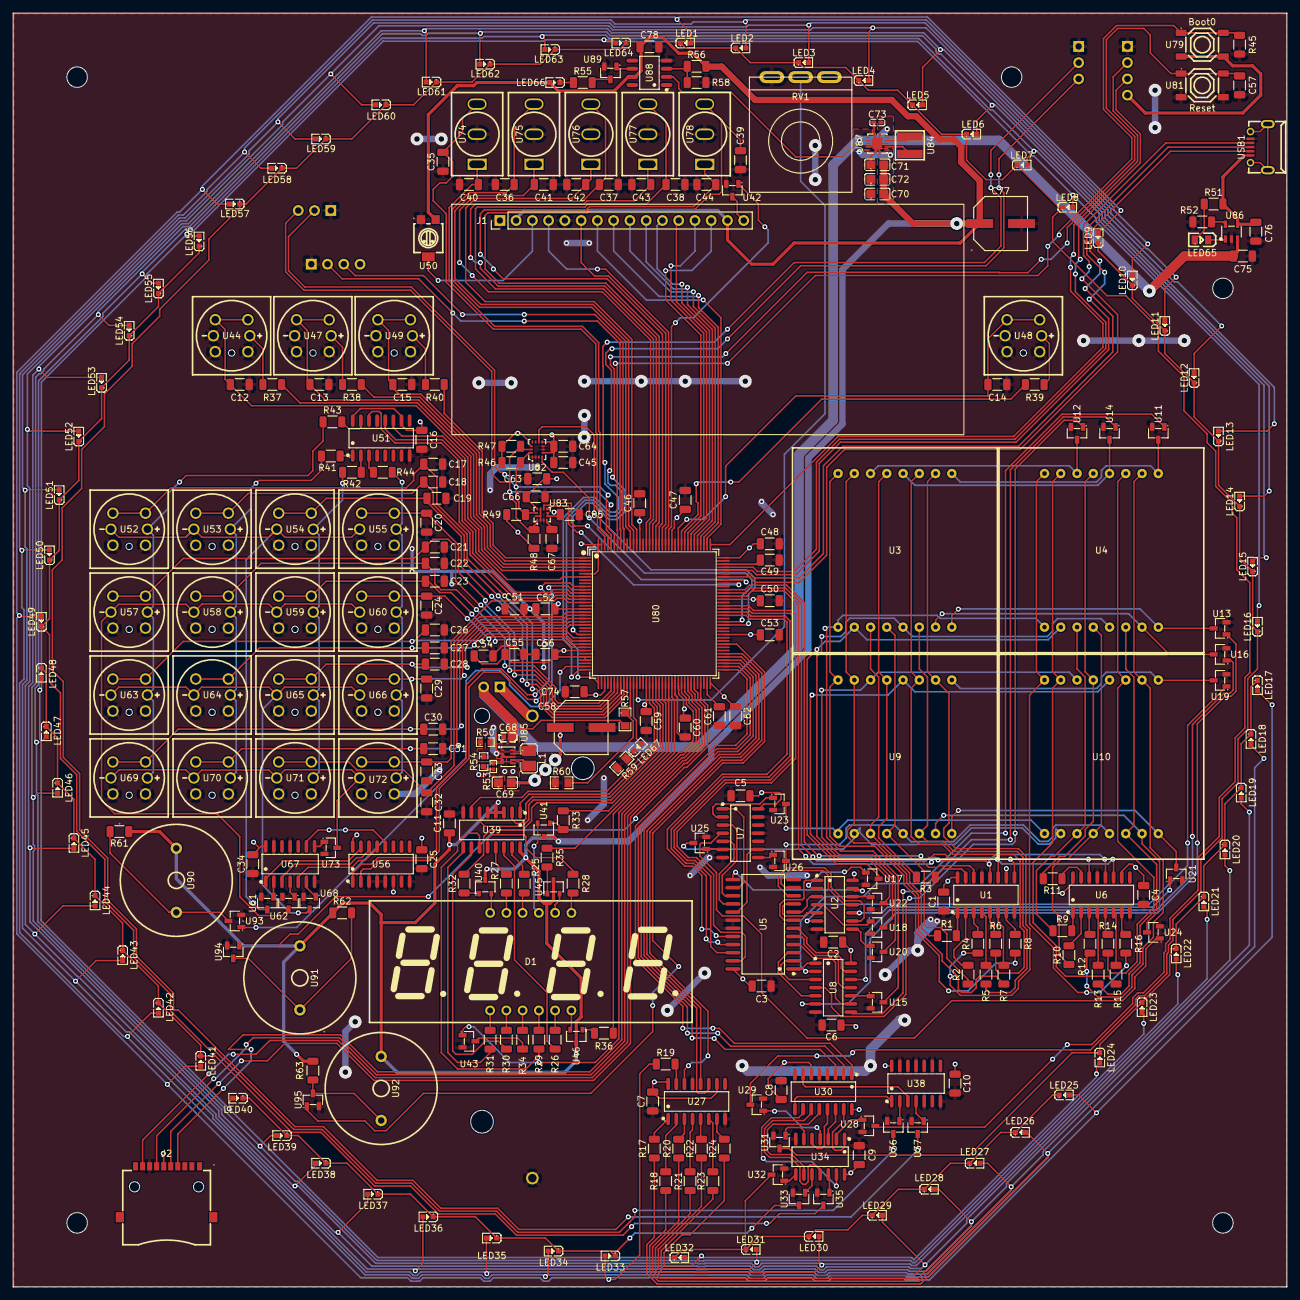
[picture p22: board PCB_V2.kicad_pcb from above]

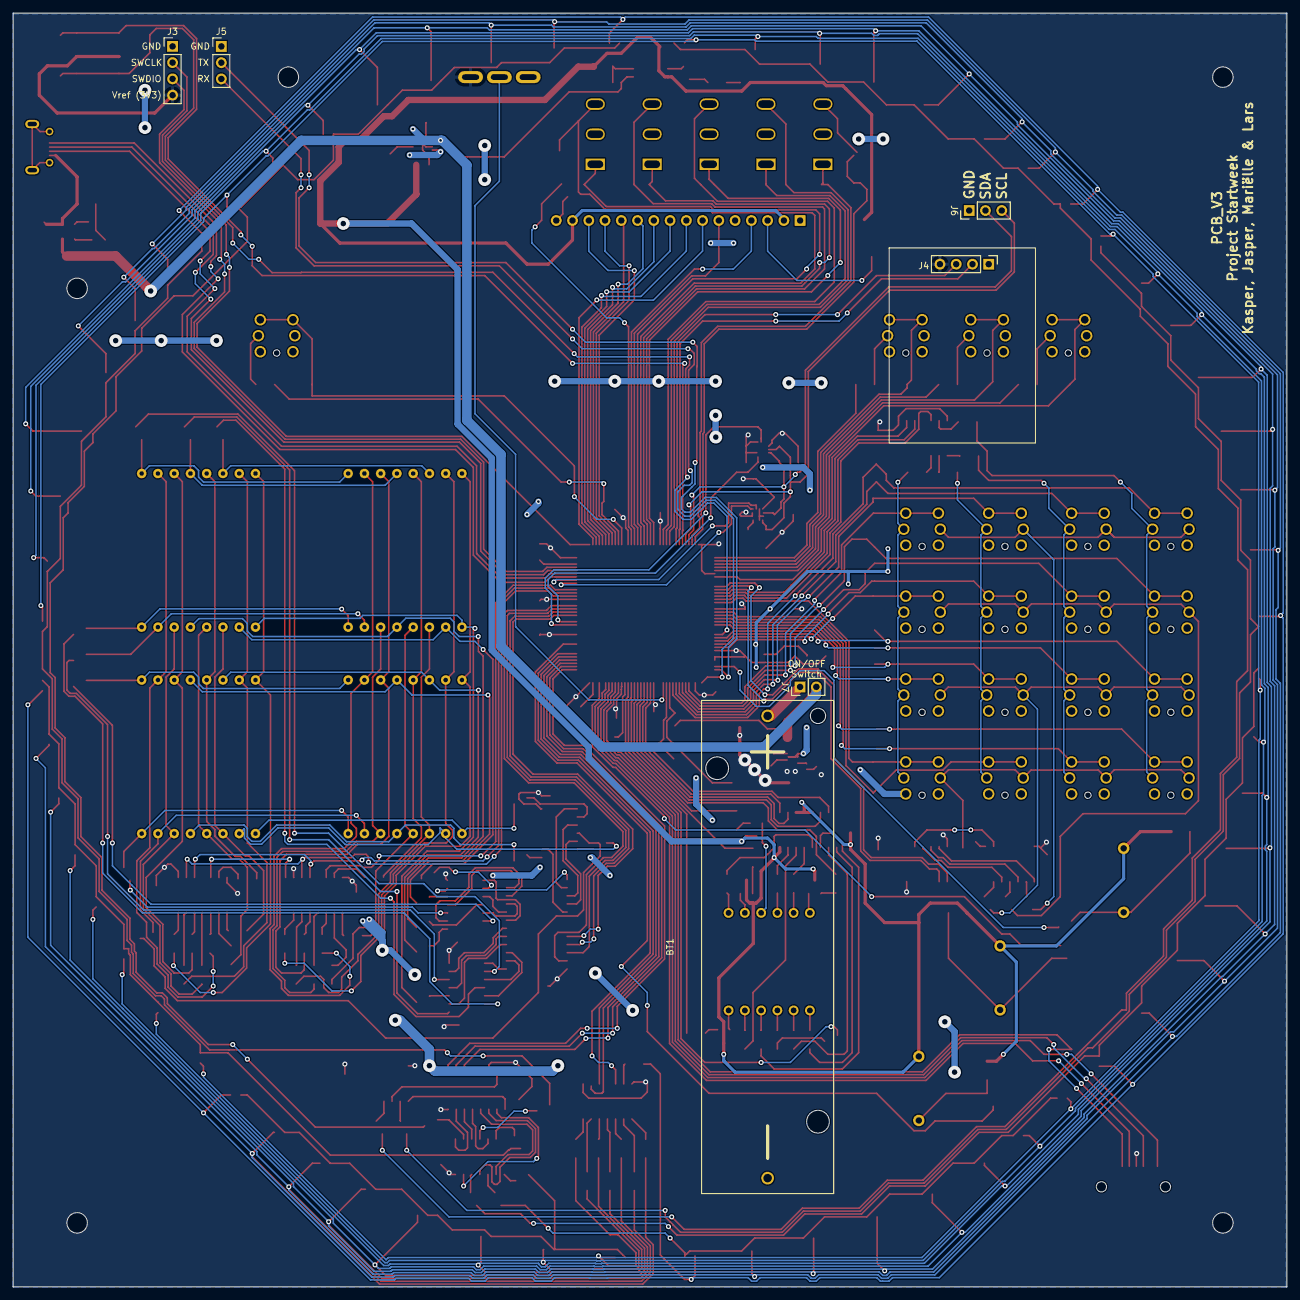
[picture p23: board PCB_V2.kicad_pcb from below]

Board: 2 copper layers, 199.0 x 199.0 mm, 315 parts (6 on the bottom side), 296 nets.

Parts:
BT1: Battery_Cell; Battery_Holder_Avans
C1, C2, C3, C4, C5, C6, C7, C8, C9, C10, C11, C12, C13, C14, C15, C16, C17, C18, C19, C20, C21, C22, C23, C24, C25, C26, C27, C28, C29, C30, C31, C32, C33, C34, C35, C36, C37, C38, C39, C40, C41, C42, C43, C44, C45, C46, C47, C48, C50, C52, C53, C55, C56, C57, C58, C59, C60, C62, C63, C64, C66, C67, C78: 100n; C_1206_3216Metric
C49, C61: 2u2; C_1206_3216Metric
C51, C75, C76: 4u7; C_1206_3216Metric
C54, C65: 1u; C_1206_3216Metric
C68: GRM188R60J226MEA0D; C0603
C69: GRM21BR61A226ME44L; C0805
C70, C71, C72: LMK212BJ106KG-T; C0805
C73: GRJ155R60J106ME11D; C0402
C74, C77: RVE1A471M0810; CAP-SMD_BD8.0-L8.3-W8.3-FD
D1: FJ5461BH-pure-red; LED-SEG-TH_FJ5461AH
J1: Conn_01x16; LCD_Display_AVANS
J2: SD-01A; SD-SMD_SD-01A
J3: Conn_01x04; PinHeader_1x04_P2.54mm_Vertical
J4: Conn_01x04; GPS_AVANS
J5, J6: Conn_01x03; PinHeader_1x03_P2.54mm_Vertical
J7: Conn_01x02; PinHeader_1x02_P2.54mm_Vertical
L1: LQM2HPNR47MG0L; L1008
LED1, LED2, LED3, LED4, LED5, LED6, LED7, LED8, LED9, LED10, LED11, LED12, LED13, LED14, LED15, LED16, LED17, LED18, LED19, LED20, LED21, LED22, LED23, LED24, LED25, LED26, LED27, LED28, LED29, LED30, LED31, LED32, LED33, LED34, LED35, LED36, LED37, LED38, LED39, LED40, LED41, LED42, LED43, LED44, LED45, LED46, LED47, LED48, LED49, LED50, LED51, LED52, LED53, LED54, LED55, LED56, LED57, LED58, LED59, LED60, LED61, LED62, LED63, LED64, LED66, LED67: KT-0603R; LED0603-RD
LED65: 17-21SUYC_TR8; LED0805-R-RD
R1, R2, R3, R4, R5, R6, R7, R8, R9, R10, R11, R12, R13, R14, R15, R16: 220; R_1206_3216Metric
R17, R18, R19, R20, R21, R22, R23, R24: 100; R_1206_3216Metric
R25, R26, R27, R28, R29, R30, R31, R34: 270; R_1206_3216Metric
R32, R33, R35, R36: 390; R_1206_3216Metric
R37, R38, R39, R40, R41, R42, R43, R44: 150; R_1206_3216Metric
R45, R46, R47, R48, R49: 10k; R_1206_3216Metric
R50: RC0603FR-0791KL; R0603
R51: 330; R_1206_3216Metric
R52: 2k2; R_1206_3216Metric
R53: CRCW0402100KFKED; R0402
R54: RC0603FR-07511KL; R0603
R55, R61, R62, R63: 470; R_1206_3216Metric
R56: 16k; R_1206_3216Metric
R57: 10k; R0805
R58: 20k; R_1206_3216Metric
R59: 200; R0805
R60: 18k; R0805
RV1: 50k; Potmeter_THT_Avans
U1, U6, U27, U51: SN74HC595DR; SOIC-16_L9.9-W3.9-P1.27-LS6.0-BL
U2, U7, U8, U34, U38, U67: SN74HC04DR; SOIC-14_L8.7-W3.9-P1.27-LS6.0-BL
U3, U4, U9, U10: SZ421288N_64; LED-SEG-TH_SZ421288N-64
U5: CD74HC154M96; SOIC-24_L15.4-W7.5-P1.27-LS10.3-BL
U11, U12, U13, U14, U15, U16, U17, U18, U19, U20, U21, U22, U23, U24, U25, U26, U28, U29, U31, U32, U33, U35, U36, U37, U42, U43, U61, U62, U68, U73, U89, U93, U94, U95: BSN20BKR; SOT-23-3_L2.9-W1.3-P1.90-LS2.4-BR
U30, U56: SN74HC138DR; SOIC-16_L9.9-W3.9-P1.27-LS6.0-BL
U39: SN74LS47DR; SOIC-16_L9.9-W3.9-P1.27-LS6.0-BL
U40, U41, U45, U46: BC817_C475629; SOT-23-3_L2.9-W1.4-P1.90-LS2.6-BR
U44, U47, U48, U49, U52, U53, U54, U55, U57, U58, U59, U60, U63, U64, U65, U66, U69, U70, U71, U72: K6-6271D04; SW-TH_K6-6271DXX
U50: 3314G-1-203E; RES-ADJ-SMD_3314G-1-103E
U74, U75, U76, U77, U78: MT-0-102-A101-M200-RS+PJ; SW-TH_MT-0-103-A101-M200-RS
U79, U81: TS-1187A-B-A-B; SW-SMD_4P-L5.1-W5.1-P3.70-LS6.5-TL-2
U80: STM32H743ZIT6; LQFP-144_L20.0-W20.0-P0.50-LS22.0-BL
U82: LSM6DSOWTR; LGA-14L_L3.0-W2.5-P0.50-TL
U83: LIS3MDLTR; LGA-12_L2.0-W2.0-P0.50-BL
U84: VLS4012ET-3R3M; IND-SMD_L4.0-W4.0_VLS4012ET
U85: TPS63802DLAR; VSON-10_L3.0-W2.0-P0.50-TL
U86: MCP73831T-2ACI_OT; SOT-23-5_L3.0-W1.7-P0.95-LS2.8-BL
U87: TPS63002DRCR; VSON-10_L3.0-W3.0-P0.50-TL-EP_TPS62410DRCR
U88: LF356MX; SOP-8_L4.9-W3.9-P1.27-LS6.0-BL
U90, U91, U92: HNR-1707; BUZ-TH_BD17.0-P10.00-D0.9
USB1: micro_USBFemale; MICRO-USB-SMD_5P-P0.65-H-F_C10418

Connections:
3D_Compass_Data_Ready: U80.101 (PA9), U83.8 (DRDY)
3D_Compass_I2C_SCL: J6.3, R47.1, R48.1, U80.139 (PB8), U82.13 (SCL), U83.1 (SCL/SPC)
3D_Compass_I2C_SDA: J6.2, R46.1, R49.1, U80.140 (PB9), U82.14 (SDA), U83.11 (SDA/SDI/SDO)
3D_Compass_Interupt: U80.100 (PA8), U83.7 (INT)
4X4_LED_Buttons_Button_1: C17.1, U52.3, U52.4, U80.46 (PB0)
4X4_LED_Buttons_Button_2: C18.1, U53.3, U53.4, U80.45 (PC5)
4X4_LED_Buttons_Button_3: C19.1, U54.3, U54.4, U80.44 (PC4)
4X4_LED_Buttons_Button_4: C20.1, U55.3, U55.4, U80.43 (PA7)
4X4_LED_Buttons_Button_5: C21.1, U57.3, U57.4, U80.42 (PA6)
4X4_LED_Buttons_Button_6: C22.1, U58.3, U58.4, U80.41 (PA5)
4X4_LED_Buttons_Button_7: C23.1, U59.3, U59.4, U80.29 (PC3_C)
4X4_LED_Buttons_Button_8: C24.1, U60.3, U60.4, U80.28 (PC2_C)
4X4_LED_Buttons_Button_9: C26.1, U63.3, U63.4, U80.27 (PC1)
4X4_LED_Buttons_Button_10: C27.1, U64.3, U64.4, U80.26 (PC0)
4X4_LED_Buttons_Button_11: C28.1, U65.3, U65.4, U80.22 (PF10)
4X4_LED_Buttons_Button_12: C29.1, U66.3, U66.4, U80.21 (PF9)
4X4_LED_Buttons_Button_13: C30.1, U69.3, U69.4, U80.20 (PF8)
4X4_LED_Buttons_Button_14: C31.1, U70.3, U70.4, U80.19 (PF7)
4X4_LED_Buttons_Button_15: C32.1, U71.3, U71.4, U80.18 (PF6)
4X4_LED_Buttons_Button_16: C33.1, U72.3, U72.4, U80.15 (PF5)
4X4_LED_Buttons_MUX_A: U56.1 (A), U80.10 (PF0)
4X4_LED_Buttons_MUX_B: U56.2 (B), U80.11 (PF1)
4X4_LED_Buttons_shift_clock: U51.11 (SRCLK), U80.12 (PF2)
4X4_LED_Buttons_shift_data_in: U51.14 (SER), U80.14 (PF4)
4X4_LED_Buttons_shift_output_enable: U51.12 (RCLK), U80.13 (PF3)
7-segment_BCD_A: U39.7 (A), U80.53 (PF13)
7-segment_BCD_B: U39.1 (B), U80.54 (PF14)
7-segment_BCD_C: U39.2 (C), U80.55 (PF15)
7-segment_BCD_D: U39.6 (D), U80.56 (PG0)
7-segment_Decimal_Point: U43.1 (G), U80.63 (PE10)
7-segment_MUX_DIG1: R32.2, U80.57 (PG1)
7-segment_MUX_DIG2: R33.2, U80.58 (PE7)
7-segment_MUX_DIG3: R35.2, U80.59 (PE8)
7-segment_MUX_DIG4: R36.2, U80.60 (PE9)
16X16_MUX_A0: U5.23 (A0), U80.93 (PG8)
16X16_MUX_A1: U5.22 (A1), U80.92 (PG7)
16X16_MUX_A2: U5.21 (A2), U80.91 (PG6)
16X16_MUX_A3: U5.20 (A3), U80.90 (PG5)
16X16_shift_clock: U1.11 (SRCLK), U6.11 (SRCLK), U80.96 (PC6)
16X16_shift_data_in: U1.14 (SER), U80.98 (PC8)
16X16_shift_output_enable: U1.12 (RCLK), U6.12 (RCLK), U80.97 (PC7)
+3V3: C1.1, C2.1, C3.1, C4.1, C5.1, C6.1, C7.1, C8.1, C9.1, C10.1, C16.1, C25.1, C34.1, C45.1, C46.1, C47.1, C48.1, C50.1, C51.1, C52.1, C53.1, C54.1, C55.1, C56.1, C58.1, C59.1, C60.1, C62.1, C63.1, C64.1, C65.1, C66.1, C69.2, C74.1, J2.4 (VDD), J3.4, J4.4, R46.2, R47.2, R48.2, R49.2, R53.2, R54.2, RV1.3, U1.10 (SRCLR#), U1.16 (VCC), U2.14 (VCC), U5.24 (VCC), U6.10 (SRCLR#), U6.16 (VCC), U7.14 (VCC), U8.14 (VCC), U27.10 (SRCLR#), U27.16 (VCC), U30.6 (G1), U30.16 (VCC), U34.14 (VCC), U38.14 (VCC), U51.10 (SRCLR#), U51.16 (VCC), U56.6 (G1), U56.16 (VCC), U67.14 (VCC), U79.3 (C), U79.4 (D), U80.6 (VBAT), U80.17 (VDD), U80.30 (VDD), U80.32 (VREF+), U80.33 (VDDA), U80.39 (VDD), U80.52 (VDD), U80.62 (VDD), U80.72 (VDD), U80.84 (VDD), U80.95 (VDDUSB), U80.108 (VDD), U80.121 (VDD), U80.131 (VDD), U80.143 (PDR_ON), U80.144 (VDD), U82.5 (VDDIO), U82.8 (VDD), U82.12 (CS), U83.5 (Vdd), U83.6 (Vdd_IO), U83.10 (CS), U85.6 (VOUT)
+5V: C11.1, C70.2, C71.2, C72.2, C77.1, C78.1, J1.2, J1.15, LED66.2 (A), R56.2, R61.1, R62.1, R63.1, U39.3 (LT#), U39.4 (BI#/RBO#), U39.5 (RBI#), U39.16 (VCC), U40.3 (C), U41.3 (C), U45.3 (C), U46.3 (C), U50.3, U87.1 (VOUT), U87.10 (FB), U88.7 (V+), U90.1, U91.1, U92.1
+BATT: C68.2, C73.2, C75.1, J7.2, R57.2, U85.1 (EN), U85.10 (VIN), U86.3 (VBAT), U87.5 (VIN), U87.6 (EN), U87.7 (PS/SYNC), U87.8 (VINA), U88.2 (-IN)
A: D1.11 (A), R27.1
ABC_Buttons_A_Button: C12.1, U44.3, U44.4, U80.7 (PC13)
ABC_Buttons_A_LED: R37.1, U80.5 (PE6)
ABC_Buttons_B_Button: C13.1, U47.3, U47.4, U80.4 (PE5)
ABC_Buttons_B_LED: R38.1, U80.3 (PE4)
ABC_Buttons_C_Button: C15.1, U49.3, U49.4, U80.2 (PE3)
ABC_Buttons_C_LED: R40.1, U80.1 (PE2)
B: D1.7 (B), R28.1
BOOT0: R45.2, U79.1 (A), U79.2 (B), U80.138 (BOOT0)
Battery_Low_LED: LED67.2 (A), U80.48 (PB2)
Battery_Voltage: R57.1, R60.2, U80.47 (PB1)
C: D1.4 (C), R29.1
D: D1.2 (D), R30.1
DEBUG_UART_RX: J5.3, U80.37 (PA3)
DEBUG_UART_TX: J5.2, U80.36 (PA2)
DIG1: D1.12 (DIG1), U40.2 (E)
DIG2: D1.9 (DIG2), U41.2 (E)
DIG3: D1.8 (DIG3), U45.2 (E)
DIG4: D1.6 (DIG4), U46.2 (E)
DP: D1.3 (DP), R34.2
E: D1.1 (E), R31.1
F: D1.10 (F), R25.1
G: D1.5 (G), R26.1
GND: BT1.2 (-), C1.2, C2.2, C3.2, C4.2, C5.2, C6.2, C7.2, C8.2, C9.2, C10.2, C11.2, C12.2, C13.2, C14.2, C15.2, C16.2, C17.2, C18.2, C19.2, C20.2, C21.2, C22.2, C23.2, C24.2, C25.2, C26.2, C27.2, C28.2, C29.2, C30.2, C31.2, C32.2, C33.2, C34.2, C35.1, C36.1, C37.1, C38.1, C39.1, C40.1, C41.1, C42.1, C43.1, C44.1, C45.2, C46.2, C47.2, C48.2, C49.2, C50.2, C51.2, C52.2, C53.2, C54.2, C55.2, C56.2, C57.2, C58.2, C59.2, C60.2, C61.2, C62.2, C63.2, C64.2, C65.2, C66.2, C67.2, C68.1, C69.1, C70.1, C71.1, C72.1, C73.1, C74.2, C75.2, C76.2, C77.2, C78.2, J1.1, J1.5, J2.6 (VSS), J3.1, J4.1, J5.1, J6.1, R45.1, R50.1, R52.1, R58.1, R59.1, R60.1, RV1.1, U1.8 (GND), U1.13 (OE#), U2.7 (GND), U5.12 (GND), U5.18 (E1#), U5.19 (E2#), U6.8 (GND), U6.13 (OE#), U7.7 (GND), U7.11 (5A), U7.13 (6A), U8.7 (GND), U11.2 (S), U12.2 (S), U13.2 (S), U14.2 (S), U15.2 (S), U16.2 (S), U17.2 (S), U18.2 (S), U19.2 (S), U20.2 (S), U21.2 (S), U22.2 (S), U23.2 (S), U24.2 (S), U25.2 (S), U26.2 (S), U27.8 (GND), U27.13 (OE#), U28.2 (S), U29.2 (S), U30.4 (G2A#), U30.5 (G2B#), U30.8 (GND), U31.2 (S), U32.2 (S), U33.2 (S), U34.7 (GND), U35.2 (S), U36.2 (S), U37.2 (S), U38.5 (3A), U38.7 (GND), U38.9 (4A), U38.11 (5A), U38.13 (6A), U39.8 (GND), U42.2 (S), U43.2 (S), U44.1, U44.2, U44.5, U47.1, U47.2, U47.5, U48.1, U48.2, U48.5, U49.1, U49.2, U49.5, U50.1, U51.8 (GND), U51.13 (OE#), U52.1, U52.2, U53.1, U53.2, U54.1, U54.2, U55.1, U55.2, U56.3 (C), U56.4 (G2A#), U56.5 (G2B#), U56.8 (GND), U57.1, U57.2, U58.1, U58.2, U59.1, U59.2, U60.1, U60.2, U61.2 (S), U62.2 (S), U63.1, U63.2, U64.1, U64.2, U65.1, U65.2, U66.1, U66.2, U67.7 (GND), U67.11 (5A), U67.13 (6A), U68.2 (S), U69.1, U69.2, U70.1, U70.2, U71.1, U71.2, U72.1, U72.2, U73.2 (S), U74.2, U75.2, U76.2, U77.2, U78.2, U80.16 (VSS), U80.31 (VSSA), U80.38 (VSS), U80.51 (VSS), U80.61 (VSS), U80.83 (VSS), U80.94 (VSS), U80.107 (VSS), U80.120 (VSS), U80.130 (VSS), U81.3 (C), U81.4 (D), U82.1 (SDO/SA0), U82.2 (SDx), U82.3 (SCx), U82.6 (GND), U82.7 (GND), U83.2 (Res), U83.3 (GND), U83.9 (SD0/SA1), U83.12 (Res), U85.2 (MODE), U85.3 (AGND), U85.8 (GND), U86.2 (VSS), U87.3 (PGND), U87.9 (GND), U87.11 (EP), U88.4 (V-), U89.2 (S), U93.2 (S), U94.2 (S), U95.2 (S), USB1.5 (V-)
GNSS_RX: J4.3, U80.136 (PB6)
GNSS_TX: J4.2, U80.137 (PB7)
Gyro_Interupt1: U80.88 (PG3), U82.4 (INT1)
Gyro_Interupt2: U80.87 (PG2), U82.9 (INT2)
LCD_Display_Backlight_Enable: U42.1 (G), U80.122 (PD6)
LCD_Display_D0: J1.7, U80.110 (PA15)
LCD_Display_D1: J1.8, U80.111 (PC10)
LCD_Display_D2: J1.9, U80.112 (PC11)
LCD_Display_D3: J1.10, U80.113 (PC12)
LCD_Display_D4: J1.11, U80.114 (PD0)
LCD_Display_D5: J1.12, U80.115 (PD1)
LCD_Display_D6: J1.13, U80.116 (PD2)
LCD_Display_D7: J1.14, U80.117 (PD3)
LCD_Display_E: J1.6, U80.124 (PG9)
LCD_Display_RS: J1.4, U80.123 (PD7)
LED_Circle_MUX_A: U30.1 (A), U80.73 (PB12)
LED_Circle_MUX_B: U30.2 (B), U80.74 (PB13)
LED_Circle_MUX_C: U30.3 (C), U80.75 (PB14)
LED_Circle_shift_clock: U27.11 (SRCLK), U80.76 (PB15)
LED_Circle_shift_data_in: U27.14 (SER), U80.78 (PD9)
LED_Circle_shift_output_enable: U27.12 (RCLK), U80.77 (PD8)
unnamed: BT1.1 (+), J7.1
unnamed: C49.1, U80.106 (Vcap_2)
unnamed: C61.1, U80.71 (Vcap_1)
unnamed: C67.1, U83.4 (C1)
unnamed: J1.3, U50.2
unnamed: J1.16, U42.3 (D)
unnamed: L1.1, U85.9 (L1)
unnamed: L1.2, U85.7 (L2)
unnamed: LED65.1 (+), R51.1
unnamed: LED65.2 (-), U86.1 (STAT)
unnamed: LED66.1 (K), R55.2
unnamed: LED67.1 (K), R59.2
unnamed: R1.2, U1.1 (QB)
unnamed: R2.2, U1.2 (QC)
unnamed: R3.1, U1.15 (QA)
unnamed: R4.2, U1.3 (QD)
unnamed: R5.2, U1.4 (QE)
unnamed: R6.2, U1.5 (QF)
unnamed: R7.2, U1.6 (QG)
unnamed: R8.2, U1.7 (QH)
unnamed: R9.2, U6.1 (QB)
unnamed: R10.2, U6.2 (QC)
unnamed: R11.1, U6.15 (QA)
unnamed: R12.2, U6.3 (QD)
unnamed: R13.2, U6.4 (QE)
unnamed: R14.2, U6.5 (QF)
unnamed: R15.2, U6.6 (QG)
unnamed: R16.2, U6.7 (QH)
unnamed: R17.2, U27.1 (QB)
unnamed: R18.2, U27.2 (QC)
unnamed: R19.1, U27.15 (QA)
unnamed: R20.2, U27.3 (QD)
unnamed: R21.2, U27.4 (QE)
unnamed: R22.2, U27.5 (QF)
unnamed: R23.2, U27.6 (QG)
unnamed: R24.2, U27.7 (QH)
unnamed: R25.2, U39.15 (f)
unnamed: R26.2, U39.14 (g)
unnamed: R27.2, U39.13 (a)
unnamed: R28.2, U39.12 (b)
unnamed: R29.2, U39.11 (c)
unnamed: R30.2, U39.10 (d)
unnamed: R31.2, U39.9 (e)
unnamed: R32.1, U40.1 (B)
unnamed: R33.1, U41.1 (B)
unnamed: R34.1, U43.3 (D)
unnamed: R35.1, U45.1 (B)
unnamed: R36.1, U46.1 (B)
unnamed: R37.2, U44.6
unnamed: R38.2, U47.6
unnamed: R39.2, U48.6
unnamed: R40.2, U49.6
unnamed: R41.1, U51.1 (QB)
unnamed: R42.1, U51.2 (QC)
unnamed: R43.2, U51.15 (QA)
unnamed: R44.1, U51.3 (QD)
unnamed: R50.2, R54.1, U85.4 (FB)
unnamed: R52.2, U86.5 (PROG)
unnamed: R53.1, U85.5 (PG)
unnamed: R55.1, U89.3 (D)
unnamed: R56.1, R58.2, U88.3 (+IN)
unnamed: R61.2, U90.2, U93.3 (D)
unnamed: R62.2, U91.2, U94.3 (D)
unnamed: R63.2, U92.2, U95.3 (D)
unnamed: U1.9 (QH#), U6.14 (SER)
unnamed: U84.1, U87.4 (L1)
unnamed: U84.2, U87.2 (L2)
unnamed: U88.6 (OUT), U89.1 (G)
Reset: C57.1, U80.25 (NRST), U81.1 (A), U81.2 (B)
Rotary_Switch: RV1.2, U80.49 (PF11)
SD_Card_CS: J2.2 (CD/DAT3), U80.64 (PE11)
SD_Card_DI: J2.3 (CMD), U80.67 (PE14)
SD_Card_DO: J2.7 (DAT0), U80.66 (PE13)
SD_Card_SCLK: J2.5 (CLK), U80.65 (PE12)
SWCLK: J3.2, U80.109 (PA14)
SWDIO: J3.3, U80.105 (PA13)
Start_Button_Button: C14.1, U48.3, U48.4, U80.119 (PD5)
Start_Button_LED: R39.1, U80.118 (PD4)
Switches_Switch_1_OFF: C40.2, U74.1, U80.141 (PE0)
Switches_Switch_1_ON: C35.2, U74.3, U80.142 (PE1)
Switches_Switch_2_OFF: C41.2, U75.1, U80.133 (PB3)
Switches_Switch_2_ON: C36.2, U75.3, U80.134 (PB4)
Switches_Switch_3_OFF: C42.2, U76.1, U80.129 (PG14)
Switches_Switch_3_ON: C37.2, U76.3, U80.132 (PG15)
Switches_Switch_4_OFF: C43.2, U77.1, U80.127 (PG12)
Switches_Switch_4_ON: C38.2, U77.3, U80.128 (PG13)
Switches_Switch_5_OFF: C44.2, U78.1, U80.125 (PG10)
Switches_Switch_5_ON: C39.2, U78.3, U80.126 (PG11)
USB_D+: U80.104 (PA12), USB1.3 (D+)
USB_D-: U80.103 (PA11), USB1.2 (D-)
USB_ID: U80.102 (PA10), USB1.4 (ID)
VBUS: C76.1, R51.2, U86.4 (VDD), USB1.1 (V+)
buzzer1: U80.35 (PA1), U93.1 (G)
buzzer2: U80.69 (PB10), U94.1 (G)
buzzer3: U80.81 (PD12), U95.1 (G)
c_1: LED1.2 (A), LED9.2 (A), LED17.2 (A), LED25.2 (A), LED33.2 (A), LED41.2 (A), LED49.2 (A), LED57.2 (A), R19.2
c_2: LED2.2 (A), LED10.2 (A), LED18.2 (A), LED26.2 (A), LED34.2 (A), LED42.2 (A), LED50.2 (A), LED58.2 (A), R17.1
c_3: LED3.2 (A), LED11.2 (A), LED19.2 (A), LED27.2 (A), LED35.2 (A), LED43.2 (A), LED51.2 (A), LED59.2 (A), R18.1
c_4: LED4.2 (A), LED12.2 (A), LED20.2 (A), LED28.2 (A), LED36.2 (A), LED44.2 (A), LED52.2 (A), LED60.2 (A), R20.1
c_5: LED5.2 (A), LED13.2 (A), LED21.2 (A), LED29.2 (A), LED37.2 (A), LED45.2 (A), LED53.2 (A), LED61.2 (A), R21.1
c_6: LED6.2 (A), LED14.2 (A), LED22.2 (A), LED30.2 (A), LED38.2 (A), LED46.2 (A), LED54.2 (A), LED62.2 (A), R22.1
c_7: LED7.2 (A), LED15.2 (A), LED23.2 (A), LED31.2 (A), LED39.2 (A), LED47.2 (A), LED55.2 (A), LED63.2 (A), R23.1
c_8: LED8.2 (A), LED16.2 (A), LED24.2 (A), LED32.2 (A), LED40.2 (A), LED48.2 (A), LED56.2 (A), LED64.2 (A), R24.1
co_1: R43.1, U52.6, U57.6, U63.6, U69.6
co_2: R41.2, U53.6, U58.6, U64.6, U70.6
co_3: R42.2, U54.6, U59.6, U65.6, U71.6
co_4: R44.2, U55.6, U60.6, U66.6, U72.6
col_1: R3.2, U3.13, U9.13
col_2: R1.1, U3.3, U9.3
col_3: R2.1, U3.4, U9.4
col_4: R4.1, U3.10, U9.10
col_5: R5.1, U3.6, U9.6
col_6: R6.1, U3.11, U9.11
col_7: R7.1, U3.15, U9.15
col_8: R8.1, U3.16, U9.16
col_9: R11.2, U4.13, U10.13
col_10: R9.1, U4.3, U10.3
col_11: R10.1, U4.4, U10.4
col_12: R12.1, U4.10, U10.10
col_13: R13.1, U4.6, U10.6
col_14: R14.1, U4.11, U10.11
col_15: R15.1, U4.15, U10.15
col_16: R16.1, U4.16, U10.16
gate_r_1: U28.1 (G), U34.2 (1Y)
gate_r_1_inv: U30.15 (Y0), U34.1 (1A)
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

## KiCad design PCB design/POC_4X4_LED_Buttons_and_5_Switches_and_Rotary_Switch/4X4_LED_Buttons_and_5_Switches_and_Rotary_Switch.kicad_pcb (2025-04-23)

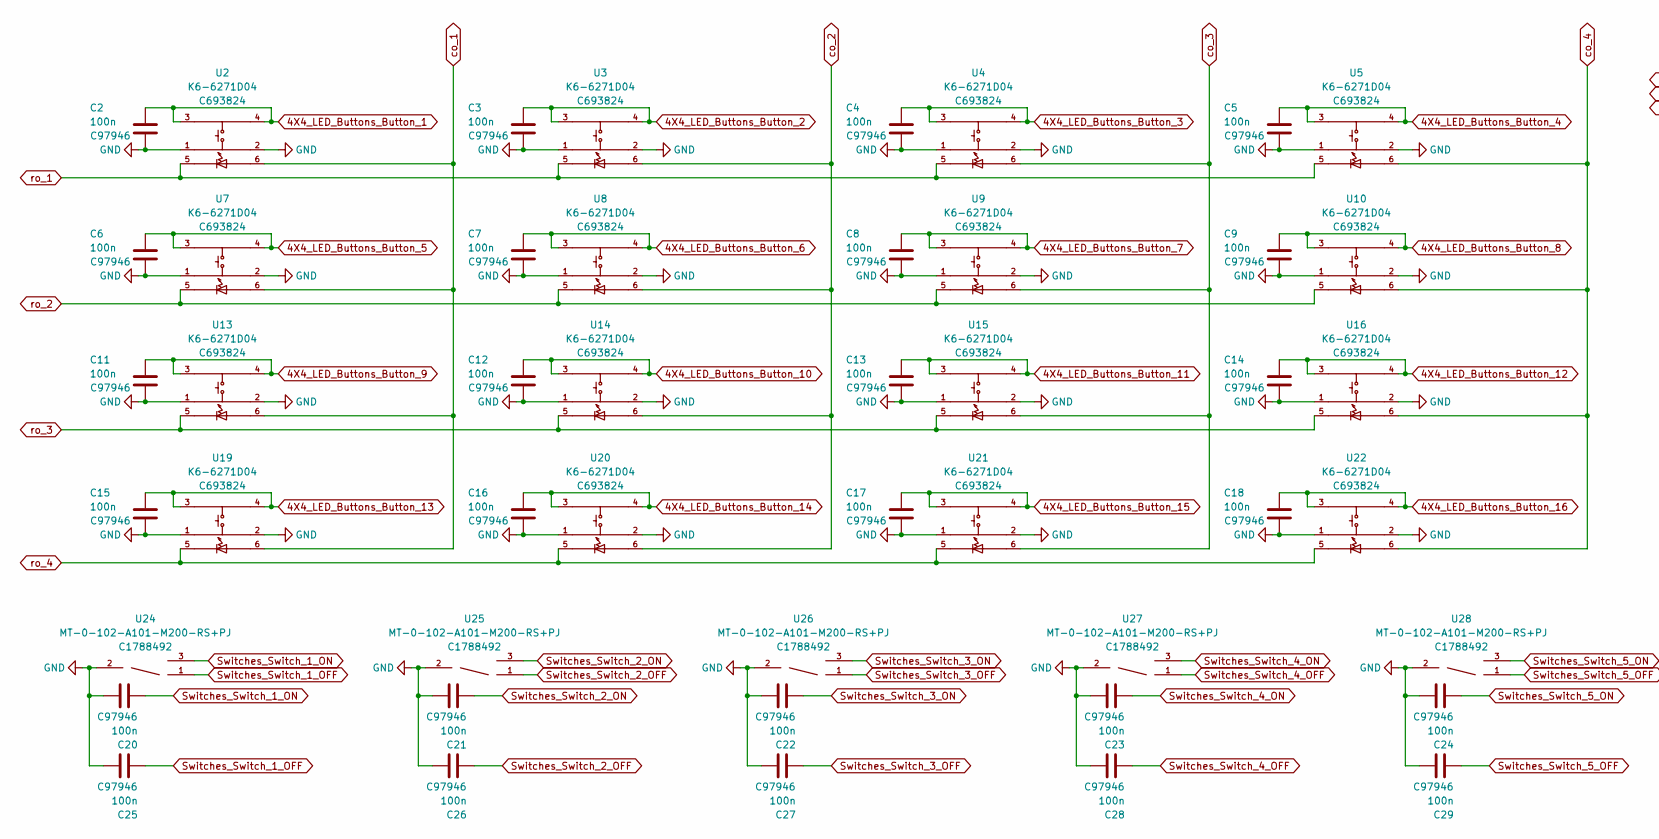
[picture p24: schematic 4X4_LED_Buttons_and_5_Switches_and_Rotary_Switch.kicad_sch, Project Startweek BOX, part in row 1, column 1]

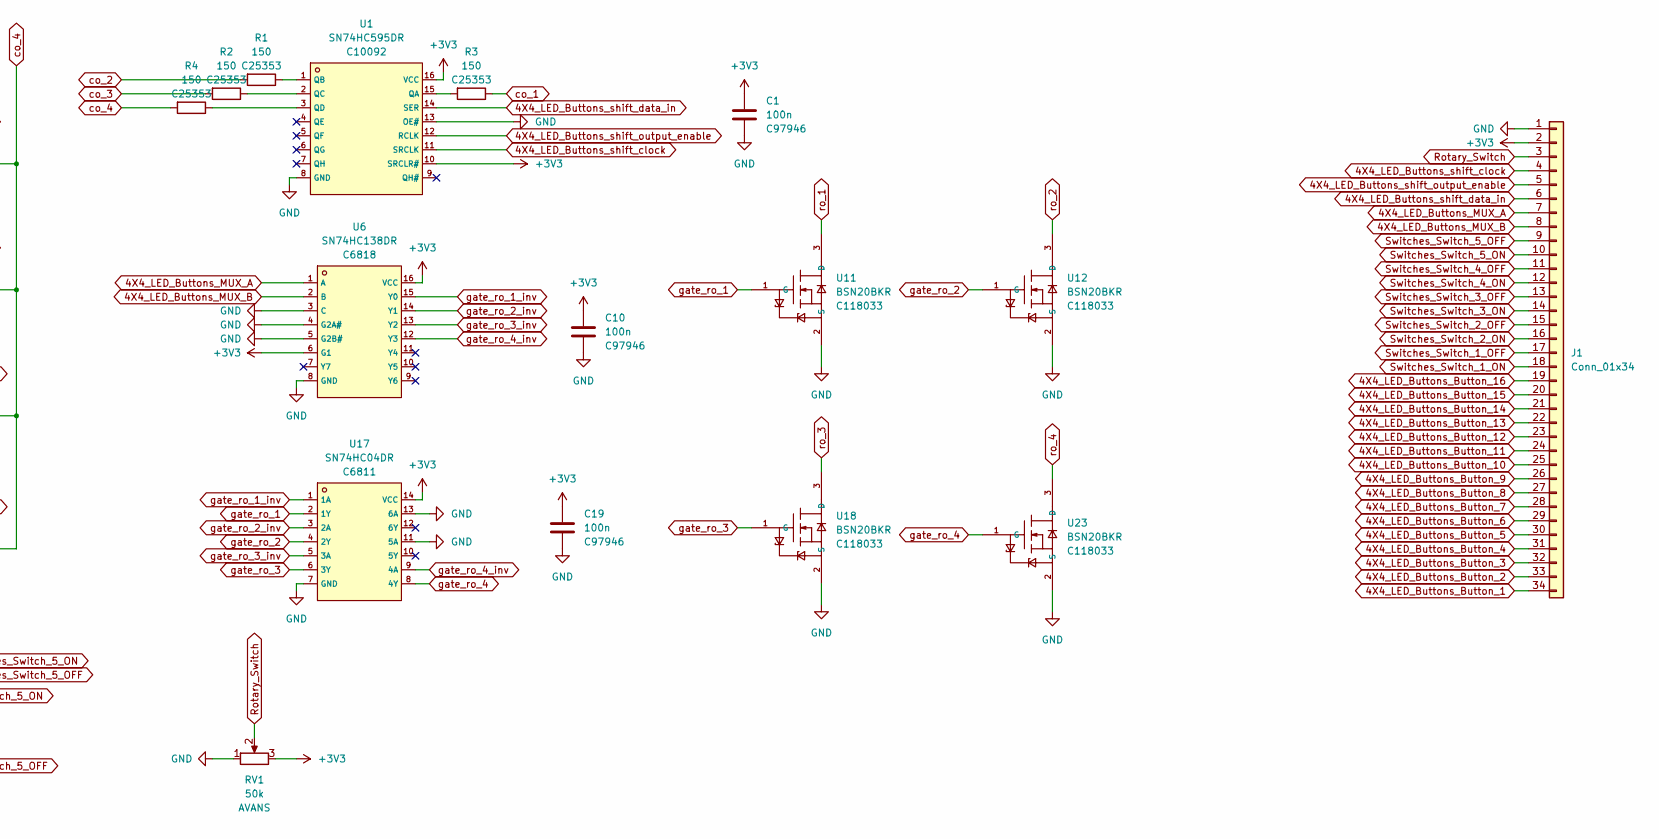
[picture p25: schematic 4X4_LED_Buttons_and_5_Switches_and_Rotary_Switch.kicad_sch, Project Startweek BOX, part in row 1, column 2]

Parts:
C1, C2, C3, C4, C5, C6, C7, C8, C9, C10, C11, C12, C13, C14, C15, C16, C17, C18, C19, C20, C21, C22, C23, C24, C25, C26, C27, C28, C29: 100n; C_1206_3216Metric; LCSC C97946
J1: Conn_01x34; PinHeader_1x34_P2.54mm_Vertical
R1, R2, R3, R4: 150; R_1206_3216Metric; LCSC C25353
RV1: 50k; Potmeter_THT_Avans; LCSC AVANS
U1: SN74HC595DR; SOIC-16_L9.9-W3.9-P1.27-LS6.0-BL; LCSC C10092
U2, U3, U4, U5, U7, U8, U9, U10, U13, U14, U15, U16, U19, U20, U21, U22: K6-6271D04; LED_Button_AVANS; LCSC C693824
U6: SN74HC138DR; SOIC-16_L9.9-W3.9-P1.27-LS6.0-BL; LCSC C6818
U11, U12, U18, U23: BSN20BKR; SOT-23-3_L2.9-W1.3-P1.90-LS2.4-BR; LCSC C118033
U17: SN74HC04DR; SOIC-14_L8.7-W3.9-P1.27-LS6.0-BL; LCSC C6811
U24, U25, U26, U27, U28: MT-0-102-A101-M200-RS+PJ; SW-TH_MT-0-103-A101-M200-RS; LCSC C1788492

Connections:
4X4_LED_Buttons_Button_1: C2.1, J1.34, U2.3, U2.4
4X4_LED_Buttons_Button_2: C3.1, J1.33, U3.3, U3.4
4X4_LED_Buttons_Button_3: C4.1, J1.32, U4.3, U4.4
4X4_LED_Buttons_Button_4: C5.1, J1.31, U5.3, U5.4
4X4_LED_Buttons_Button_5: C6.1, J1.30, U7.3, U7.4
4X4_LED_Buttons_Button_6: C7.1, J1.29, U8.3, U8.4
4X4_LED_Buttons_Button_7: C8.1, J1.28, U9.3, U9.4
4X4_LED_Buttons_Button_8: C9.1, J1.27, U10.3, U10.4
4X4_LED_Buttons_Button_9: C11.1, J1.26, U13.3, U13.4
4X4_LED_Buttons_Button_10: C12.1, J1.25, U14.3, U14.4
4X4_LED_Buttons_Button_11: C13.1, J1.24, U15.3, U15.4
4X4_LED_Buttons_Button_12: C14.1, J1.23, U16.3, U16.4
4X4_LED_Buttons_Button_13: C15.1, J1.22, U19.3, U19.4
4X4_LED_Buttons_Button_14: C16.1, J1.21, U20.3, U20.4
4X4_LED_Buttons_Button_15: C17.1, J1.20, U21.3, U21.4
4X4_LED_Buttons_Button_16: C18.1, J1.19, U22.3, U22.4
4X4_LED_Buttons_MUX_A: J1.7, U6.1 (A)
4X4_LED_Buttons_MUX_B: J1.8, U6.2 (B)
4X4_LED_Buttons_shift_clock: J1.4, U1.11 (SRCLK)
4X4_LED_Buttons_shift_data_in: J1.6, U1.14 (SER)
4X4_LED_Buttons_shift_output_enable: J1.5, U1.12 (RCLK)
+3V3: C1.1, C10.1, C19.1, J1.2, RV1.3, U1.10 (SRCLR#), U1.16 (VCC), U6.6 (G1), U6.16 (VCC), U17.14 (VCC)
GND: C1.2, C2.2, C3.2, C4.2, C5.2, C6.2, C7.2, C8.2, C9.2, C10.2, C11.2, C12.2, C13.2, C14.2, C15.2, C16.2, C17.2, C18.2, C19.2, C20.1, C21.1, C22.1, C23.1, C24.1, C25.1, C26.1, C27.1, C28.1, C29.1, J1.1, RV1.1, U1.8 (GND), U1.13 (OE#), U2.1, U2.2, U3.1, U3.2, U4.1, U4.2, U5.1, U5.2, U6.3 (C), U6.4 (G2A#), U6.5 (G2B#), U6.8 (GND), U7.1, U7.2, U8.1, U8.2, U9.1, U9.2, U10.1, U10.2, U11.2 (S), U12.2 (S), U13.1, U13.2, U14.1, U14.2, U15.1, U15.2, U16.1, U16.2, U17.7 (GND), U17.11 (5A), U17.13 (6A), U18.2 (S), U19.1, U19.2, U20.1, U20.2, U21.1, U21.2, U22.1, U22.2, U23.2 (S), U24.2, U25.2, U26.2, U27.2, U28.2
unnamed: R1.1, U1.1 (QB)
unnamed: R2.1, U1.2 (QC)
unnamed: R3.2, U1.15 (QA)
unnamed: R4.1, U1.3 (QD)
Rotary_Switch: J1.3, RV1.2
Switches_Switch_1_OFF: C25.2, J1.17, U24.1
Switches_Switch_1_ON: C20.2, J1.18, U24.3
Switches_Switch_2_OFF: C26.2, J1.15, U25.1
Switches_Switch_2_ON: C21.2, J1.16, U25.3
Switches_Switch_3_OFF: C27.2, J1.13, U26.1
Switches_Switch_3_ON: C22.2, J1.14, U26.3
Switches_Switch_4_OFF: C28.2, J1.11, U27.1
Switches_Switch_4_ON: C23.2, J1.12, U27.3
Switches_Switch_5_OFF: C29.2, J1.9, U28.1
Switches_Switch_5_ON: C24.2, J1.10, U28.3
co_1: R3.1, U2.6, U7.6, U13.6, U19.6
co_2: R1.2, U3.6, U8.6, U14.6, U20.6
co_3: R2.2, U4.6, U9.6, U15.6, U21.6
co_4: R4.2, U5.6, U10.6, U16.6, U22.6
gate_ro_1: U11.1 (G), U17.2 (1Y)
gate_ro_1_inv: U6.15 (Y0), U17.1 (1A)
gate_ro_2: U12.1 (G), U17.4 (2Y)
gate_ro_2_inv: U6.14 (Y1), U17.3 (2A)
gate_ro_3: U17.6 (3Y), U18.1 (G)
gate_ro_3_inv: U6.13 (Y2), U17.5 (3A)
gate_ro_4: U17.8 (4Y), U23.1 (G)
gate_ro_4_inv: U6.12 (Y3), U17.9 (4A)
ro_1: U2.5, U3.5, U4.5, U5.5, U11.3 (D)
ro_2: U7.5, U8.5, U9.5, U10.5, U12.3 (D)
ro_3: U13.5, U14.5, U15.5, U16.5, U18.3 (D)
ro_4: U19.5, U20.5, U21.5, U22.5, U23.3 (D)

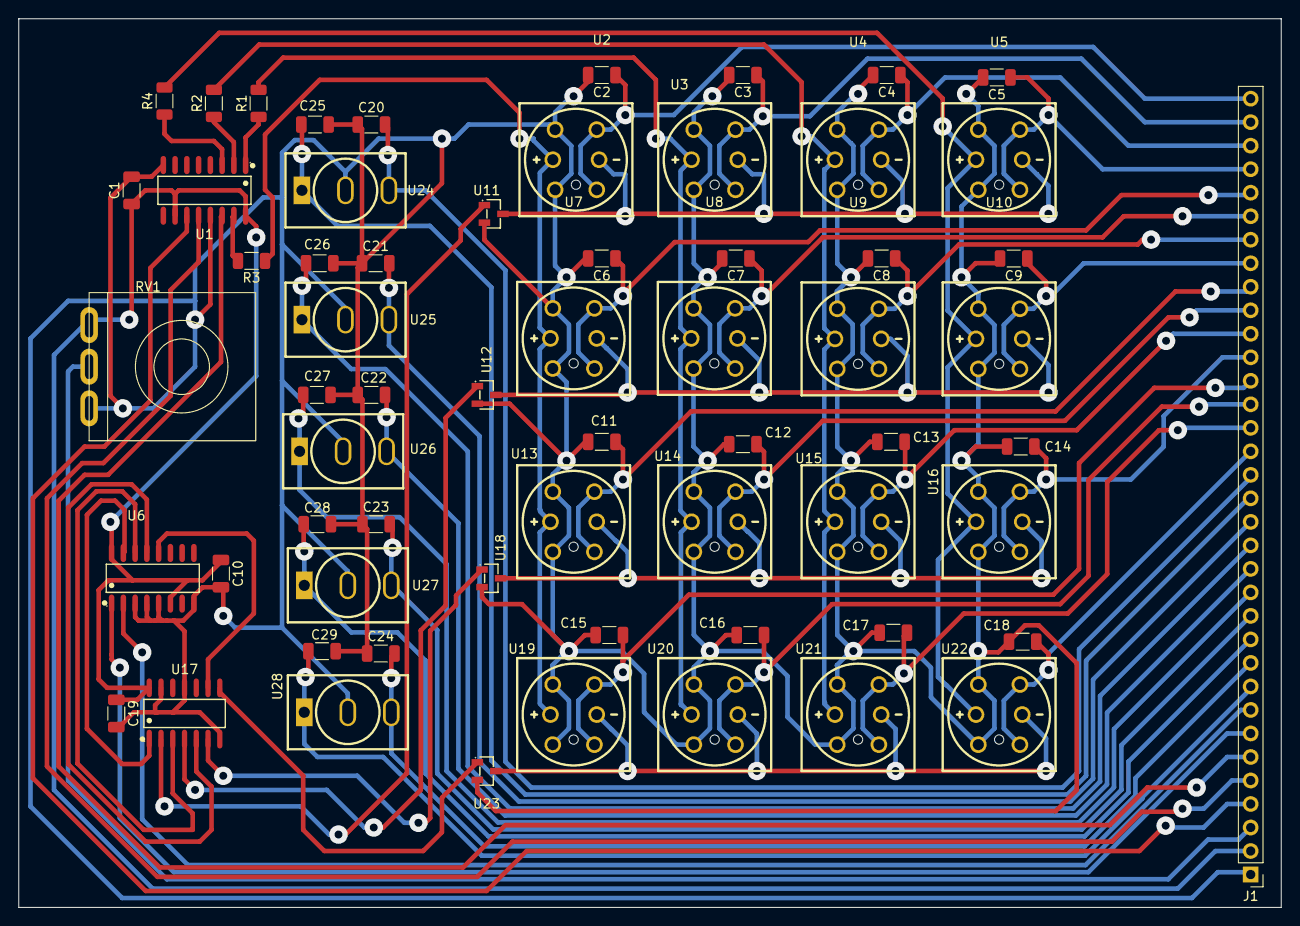
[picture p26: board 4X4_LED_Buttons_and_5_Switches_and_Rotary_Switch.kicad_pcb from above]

Board: 2 copper layers, 136.4 x 96.0 mm, 63 parts (0 on the bottom side), 54 nets.

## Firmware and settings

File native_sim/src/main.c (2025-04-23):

/*
 * SPDX-License-Identifier: Apache-2.0
 */


#include <zephyr/device.h>
#include <zephyr/devicetree.h>
#include <zephyr/drivers/display.h>
#include <zephyr/drivers/gpio.h>

#include <stdio.h>
#include <string.h>
#include <zephyr/kernel.h>

////////////////////////////////////////////////////////////////////
/// TESTING!!!
#include "testHandler.h"
///////////////////////////////////////////////////////////////////

#include "statemachine.h"
#include "threads.h"

#ifdef CONFIG_BOARD_NATIVE_SIM
#include "lvgl_ui.h"
#include <lvgl.h>
#include <lvgl_input_device.h>

#endif



#define LOG_LEVEL CONFIG_LOG_DEFAULT_LEVEL
#include <zephyr/logging/log.h>
LOG_MODULE_REGISTER(app);

// The stack size of all threads
#define STACKSIZE 1024

//LVGL stack
#define STACKSIZE2 16000

// Thread priority values (lower value is higher priority)
#define TMAIN_PRIORITY 9
#define TLVGL_PRIORITY 3

#ifdef CONFIG_BOARD_NATIVE_SIM 

void lvgl_task_handler_loop() {
    while (1) {
		//k_cpu_idle();
        lv_task_handler();
		//for native_sim
        k_sleep(K_MSEC(1));
    }
}

#endif

int tmain() // Core thread
{
	#ifdef CONFIG_BOARD_NATIVE_SIM 
	const struct device *display_dev;
	display_dev = DEVICE_DT_GET(DT_CHOSEN(zephyr_display));
	if (!device_is_ready(display_dev)) {
		LOG_ERR("Device not ready, aborting test");
		return 0;
	}

	//lv_task_handler();
	display_blanking_off(display_dev);

	setup_ui(lv_scr_act());

	printf("Main\n");
	#endif

	///////////////////////////////////////////////////
	/// TEST before statemachine

	if(handleTests() != 0)
	{
		printk("Error!\n");
	}
	
	///////////////////////////////////////////////////


	startStatemachine();

	return 0;
}

// Define the threads
K_THREAD_DEFINE(tmain_id, STACKSIZE, tmain, NULL, NULL, NULL, TMAIN_PRIORITY, 0, 0);
#ifdef CONFIG_BOARD_NATIVE_SIM
K_THREAD_DEFINE(tlvgl_id, STACKSIZE2, lvgl_task_handler_loop, NULL, NULL, NULL, TLVGL_PRIORITY, 0, 0);
#endif

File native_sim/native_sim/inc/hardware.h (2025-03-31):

#ifndef HARDWARE_H
#define HARDWARE_H

#include <zephyr/drivers/gpio.h>
#include <stdio.h>
#include <zephyr/kernel.h>

#define LEDMATRIXLEDSINROW		16
#define LEDMATRIXROWS 			16
#define CIRCLEMATRIXLEDSINROW		8
#define CIRCLEMATRIXROWS 			8
#define BUTTONMATRIXLEDSINROW		4
#define BUTTONMATRIXROWS 			4

#ifndef HIGH
#define HIGH 1
#endif

#ifndef LOW
#define LOW 0
#endif

static const struct gpio_dt_spec abcbutton[3] = {
	GPIO_DT_SPEC_GET(DT_ALIAS(sw16), gpios),
	GPIO_DT_SPEC_GET(DT_ALIAS(sw17), gpios),
	GPIO_DT_SPEC_GET(DT_ALIAS(sw18), gpios),
};

static const struct gpio_dt_spec buttonsButtonMatrix[16] = {
	GPIO_DT_SPEC_GET(DT_ALIAS(sw0), gpios),
	GPIO_DT_SPEC_GET(DT_ALIAS(sw1), gpios),
	GPIO_DT_SPEC_GET(DT_ALIAS(sw2), gpios),
	GPIO_DT_SPEC_GET(DT_ALIAS(sw3), gpios),
	GPIO_DT_SPEC_GET(DT_ALIAS(sw4), gpios),
	GPIO_DT_SPEC_GET(DT_ALIAS(sw5), gpios),
	GPIO_DT_SPEC_GET(DT_ALIAS(sw6), gpios),
	GPIO_DT_SPEC_GET(DT_ALIAS(sw7), gpios),
	GPIO_DT_SPEC_GET(DT_ALIAS(sw8), gpios),
	GPIO_DT_SPEC_GET(DT_ALIAS(sw9), gpios),
	GPIO_DT_SPEC_GET(DT_ALIAS(sw10), gpios),
	GPIO_DT_SPEC_GET(DT_ALIAS(sw11), gpios),
	GPIO_DT_SPEC_GET(DT_ALIAS(sw12), gpios),
	GPIO_DT_SPEC_GET(DT_ALIAS(sw13), gpios),
	GPIO_DT_SPEC_GET(DT_ALIAS(sw14), gpios),
	GPIO_DT_SPEC_GET(DT_ALIAS(sw15), gpios)
};

static const struct gpio_dt_spec switchon[5] = {
	GPIO_DT_SPEC_GET(DT_ALIAS(sw19), gpios),
	GPIO_DT_SPEC_GET(DT_ALIAS(sw20), gpios),
	GPIO_DT_SPEC_GET(DT_ALIAS(sw21), gpios),
	GPIO_DT_SPEC_GET(DT_ALIAS(sw22), gpios),
	GPIO_DT_SPEC_GET(DT_ALIAS(sw23), gpios),
};

static const struct gpio_dt_spec switchoff[5] = {
	GPIO_DT_SPEC_GET(DT_ALIAS(sw24), gpios),
	GPIO_DT_SPEC_GET(DT_ALIAS(sw25), gpios),
	GPIO_DT_SPEC_GET(DT_ALIAS(sw26), gpios),
	GPIO_DT_SPEC_GET(DT_ALIAS(sw27), gpios),
	GPIO_DT_SPEC_GET(DT_ALIAS(sw28), gpios),
};

static const struct gpio_dt_spec startbutton	= GPIO_DT_SPEC_GET(DT_ALIAS(sw29), gpios);

uint8_t abcbuttonsInit();
bool buttons4x4Config();
uint8_t buttons4x4Init();
uint8_t switchesInit();

uint8_t lcdStringWrite(char *msg);
uint8_t lcdEnable();
uint8_t lcdClear();
uint8_t lcdDisable();

uint8_t abcbuttonsGet(char selectedbtn);
uint8_t buttons4x4Get(uint8_t selectedbtn);
uint8_t buttons4x4GetLVGL(uint8_t selectedbtn);
uint8_t switchesGet(uint8_t selectedswitch);
uint8_t startbuttonGet();

uint8_t abcledsSet(char selectedled,bool value);
uint8_t buttonMatrixSet(uint8_t data[BUTTONMATRIXROWS]);
uint8_t circleMatrixSet(uint8_t data[8]);
int8_t ledMatrixSet(int16_t data[16]);
uint8_t sevenSegmentSet(char input[4],uint8_t dpPosition);
uint8_t startledSet(bool value);

#endif // HARDWARE_H

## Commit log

2025-04-23 Added tests for sim and hardware. For all existing drivers. Possibly some slight issues on hardware as it is not tested for hardware yet.
    [buttonMatrix.c, main.c]
2025-04-23 Added tests for sim and hardware for all existing drivers. Possibly some slight issues on hardware as it is not yet tested.
    [buttonMatrix.c, main.c]
